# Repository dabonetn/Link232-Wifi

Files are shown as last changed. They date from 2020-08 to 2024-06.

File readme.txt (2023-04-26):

Usage Notes

BBS Host Mode.
The current BBS host mode enables a local echo by default, so to make it actually work with bbs software, when you enable
bbs host in the at+config menu, in the bbs host submenu, make sure echo is set to off.

128 Users. I noticed on DESTERM and Dialogue 128, that if you have the modem set to hangup on DTR drop,
the modem will hang up trying to download. To disable this function, enter the command
ats54=2 then press enter, then at&w then enter to save it to the modem.
After this, you have to use the +++, wait and then ATH for hangup on your side.

Main Readme.

Link232-Wifi, Swift-L and Swift-T

This project covers the Link232 and Swiftlink RS232 carts combined with the zimodem firmware.
It has my Cartridge version, along with the Internal Versions for the 128, 128DCR and C64 longboard.

Link232-Wifi
This is a Swiftlink compatible High Speed Uart cartridge for the Commodore 64/128.
Because it's a link232 clone, it only uses 16 bytes of the dXXX address space, and you can set it using the solder jumpers. 
You must cut the dx00 link and then connect the solder jumper you want the new address to be.

Swift-T
This is a Swiftlink compatible internal wifi modem for the c64 longboard and the 128DCR.
It plugs into a socket at U2 and then you install the 6526 into the modem board.
Flying leads then connect the IO address (DE00 or DF00) and Dotclock.
On the 128DCR, it plugs in U1, and has one more flying lead to connect the NMI line. (Total of 3)

Swift-L
This is a Swiftlink compatible internal wifi modem for the C128 flat model.
It plugs into a socket at U2 and then you install the 6526 into the modem board.
Flying leads then connect the IO address (DE00/DF00/Or D700) and Dotclock.

All of them use swiftlink drivers in your favorite terminal program/bbs.
CCGMS/Novaterm/Desterm/etc.. 

For Centipede 128 BBS software, new Swiftlink drivers for address DF00 and D700 are located under the SoftwarePatches directory.
(It only had DE00 by default)

Premade units are usually available on ebay from me.

https://www.ebay.com/sch/tndabone/m.html?_nkw=&_armrs=1&_ipg=&_from=

Default for most programs is DE00/NMI

Modem commands are under the Zimodem directory.

I'm merging the Internal Units and the Cartridge version under this page. As all 3 use the same firmware.

Much thanks to Dr. Evil Laboratories for designing the original Swiftlink Cart.
And to Jim Brain for the Link232 design,
And of course Bo Zimmerman for the very excellent Zimodem firmware.

Please see the quick start guide if you bought a prebuilt cart.

Default setting for a new unit from me is.

DE00/NMI

19200 Baud
Hardware Flow Control (CTS/RTS)

The current zimodem firmware is forked from version "3.7.0"

To update to the current firmware use the command

at&u6502

For usage of zimodem, see the readme in the zimodem directory.
Link232-Wifi is based off the ESP-12, not the ESP32, so No esp32 only features will work.

Changes I've made.

In Zimodem.ino I've set 19200 baud as standard, and got rid of the signal inversion while using a ESP8266 module.

Zcommand.ino mainly has me replacing the zimmers.net with dabone.xyz to prevent a update and bricking of the Link232-Wifi.
Telnet protocol on atdt dialing has been disabled by default ""telnetSupport=false;""
To renable telnet translation by the modem instead of the terminal, use the command ats62=1.

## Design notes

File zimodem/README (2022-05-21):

Zimodem 3.6.4 (C)2016-2021 Bo Zimmerman
Please read the LICENSE file for license information
Please read the NOTICE file for credits information

Intro:
------
This firmware code provides an api for communication between a serial terminal and the ESP8266 or ESP32.  It simulates the old-style Hayes "AT" commands, so that the ESP8266 appears to the terminal as if it were a Hayes modem.  These "AT" commands may then be issued to the ESP8266 in order to force it to connect to a wireless access point, and from there to make one or more manageable connections to the internet.  It also includes a streaming serial "telnet" mode, and server/port listener capabilities.

The default baud rate that the firmware establishes is 1200.  Be sure to use the commands below to set this to the proper baud rate for your terminal/host computer.  If you plan on using the Commodore 8-bit utilities, keep the firmware baud rate saved at 1200.

Building:
---------
To build this firmware for the ESP-01 or ESP-12, I used the Arduino IDE rev1.8.10 with the 2.7.4 Arduino ESP8266 libraries using the Generic ESP8266 Module.  Versions newer than 2.7.4 may not work.  Install the libraries from the Boards Manager using http://arduino.esp8266.com/stable/package_esp8266com_index.json. Both versions of the firmware are built with SPIFFS enabled.  On the ESP8266, I used settings of 1M/160k, but you may want to alter that depending on your hardware and needs. 

To build this firmware for the ESP-32, I also used the Arduino IDE rev 1.8.10 with the Arduino ESP32 Dev Module installed from the board manager * , with the following settings: QIO, 4MB, 80MHZ, 921600, NONE, Avrisp Mk II **.  I found that baud changing corrupts the serial bus as of 1/13/2018, so the following changes were made to the base libraries: 
> Added to esp32-hal-uart.c:
void uartChangeBaudRate(uint8_t uart_nr, uint32_t baudrate)
{ 
    uartSetBaudRate(&_uart_bus_array[uart_nr], baudrate); 
}
void uartChangeConfig(uint8_t uart_nr, uint32_t config)
{
    uart_t* uart = &_uart_bus_array[uart_nr];
    UART_MUTEX_LOCK();
    uart->dev->conf0.val = config;
    #define TWO_STOP_BITS_CONF 0x3
    #define ONE_STOP_BITS_CONF 0x1

    if ( uart->dev->conf0.stop_bit_num == TWO_STOP_BITS_CONF) {
        uart->dev->conf0.stop_bit_num = ONE_STOP_BITS_CONF;
        uart->dev->rs485_conf.dl1_en = 1;
    }
    UART_MUTEX_UNLOCK();
}
size_t uartWritesRemaining(uart_t* uart)
{
    if(uart == NULL) {
        return 0;
    }
    size_t remain;
    UART_MUTEX_LOCK();
    remain = 0x7F - uart->dev->status.txfifo_cnt;
    UART_MUTEX_UNLOCK();
    return remain;
}
> Added to esp32-hal-uart.h:
void uartChangeBaudRate(uint8_t uart_nr, uint32_t baudrate);
void uartChangeConfig(uint8_t uart_nr, uint32_t config);
size_t uartWritesRemaining(uart_t* uart);
> Added to HardwareSerial.cpp:
void HardwareSerial::changeBaudRate(int baudRate) { uartChangeBaudRate(_uart_nr, baudRate); }
void HardwareSerial::changeConfig(uint32_t config) { uartChangeConfig(_uart_nr, config); }
> Added to HardwareSerial.h:
void changeBaudRate(int baudRate);
void changeConfig(uint32_t config);

* On the ESP32, if you want to build firmware that is Update compatible with the official production zimodem, you'll need to install the exact libraries I use from http://www.zimmers.net/otherprojs/esp32_v0.zip .  If you don't care about that, using the latest libs work just fine.

Using:
------
Upon initialization, or any time the ESP module is reset, the modem will display its version, and some information about the host hardware, and then read a configuration file from the internal SPIFFS to re-establish the previously set baud rate, and to attempt to re-connect to the previously connected wireless router.  The first time it is run, the firmware will set a baud rate of 1200 and display INITALIZED to let you know that no previous wifi configuration was found.  Once the serial terminal displays READY, it is ready to receive commands.  

The first command you'll probably want to enter is AT+CONFIG to connect to a wireless router, and set your flow control and other command mode settings.

Afterwards, if you plan to use this primarily from a computer that doesn't need linefeeds, such as the C64, you'll want to enter ATR0 to go into carriage-return only mode, and then at&w to save this setting as well.

If you want to operate at a higher baud, you'll want to enter ATB9600 (or whatever baud rate you want to try), and then reconnect your terminal program to the modem at that new baud rate.  If everything looks good, and you want to keep the new baud rate across restarts, save the new baud rate with AT&W.  Warning though: Most of the example C64 programs assume the modem defaults to 1200 baud.

If you want to connect to a remote telnet server, eg coffeemud.net, port 23, you'll want to enter ATDT"coffeemud.net:23".  Don't forget to set your terminal program to the proper translation mode (ANSI, ASCII, or whatever).

If you are using a Commodore Graphics terminal program and want to connect to a Commodore BBS, eg cottonwoodbbs.dyndns.org port 6502, you'll want to enter ATD"cottonwoodbbs.dyndns.org:6502".

If you want to use Q-Link, you need to add a phone number alias first.  To do this, enter ATP"5551212=q-link.net:5190" or enter it from the config menu AT+CONFIG. From the C64 Q-Link client, select "Hayes compatible" 1200 baud modem when prompted.

If you want to run a Commodore BBS program using the modem, you'll want to configure the BBS program to the same idle baud rate that your modem is using (1200 baud by default), configure it for a Hayes style modem (or the C=1670), and either create a persistant listener using AT+CONFIG, or use an initialization string of "ATR0E0S0=1S41=1A6400" plus any other recommended settings from the BBS program. This creates a listener at port 6400 that switches directly to stream mode on the first ring, with no linefeed carriage returns, and no keystroke echo.  Your BBS program may require you add certain other settings, such as V0 or X1.. which you should also do.

If you want to try printing to a CUPS/IPP-printer, enter AT+PRINT?:<host>:<port>/<path>, followed by your data.  Where ? is A)scii, P)etscii, or R)aw.  A 5 second pause in incoming data completes the document and returns to command mode.  Example: AT+PRINTR:192.168.1.10:631/ipp/printer  -- followed by ENTER and then the data to print, without any pause longer than 5 seconds.  Subsequent to doing this, using AT+PRINT will repeat the previous URL.

ESP32 Guru Modem users with SD-cards can enter AT+SHELL to get a shell command prompt.  Enter ? to get a list of shell commands.

Command Set:
-----------

The command set is as follows (not case sensitive):

ATZ : closes all open socket connections (preserving the Access Point connection), stops all listeners, and resets the state of the Command processor to the saved configuration, preserving the current baud rate and wifi connection.

A/ : Repeats the previous command

ATI : re-shows the startup message, including wifi connection information.
ATI0 : same as ATI
ATI1 : Shows the current common variable settings, common 'S' registers.
ATI2 : Shows the modem's current IP address
ATI3 : Shows the modem's current Wireless Router connection
ATI4 : Shows only the firmware current version
ATI5 : Shows all the current variable settings, all 'S' registers.
ATI6 : Shows the current mac address.
ATI7 : Shows the current formatted time (see AT&T).
ATI8 : Shows the firmware build date/time
ATI9 : Same as I3, but also includes any static settings, same order as ATW
ATI10: Shows the last printer url used.

ATA  : If a server listener has generated a RING, then ATA will switch the last rung connection to Stream mode (see ATD).

ATAn : Causes the modem to create a server listening on port n.  When a connection is received, the terminal will generate 1 or more RINGs according to the ATS0 register, followed by a normal CONNECT respose. At this point, all other commands related to connections may be used normally, unless ATS41 is > 0, in which case incoming connections are automatically sent to Stream mode as per ATD or ATA. Listeners are listed along with other connections using ATC0.
ATAPn : Adding a P modifier causes all incoming connection input to be translated to PETSCII
ATATn : Adding a T modifier causes connection streaming input to be translated per TELNET when the changed to Stream mode
ATAEn : Adding a E modifier causes connection terminal echo to be enabled when the changed to Stream mode
ATAXn : Adding a X modifier causes connection XON/XOFF flow control to be enabled  when the changed to Stream mode.

ATN0 : Shuts down all listeners, leaving client connections open
ATNn : if n > 0 then same as ATAn

ATE0 : Turns serial terminal echo off for command mode.
ATE1 : Turns serial terminal echo on for command mode.

ATV0 : Turns off verbose responses mode (Uses Terse Numeric response mode)
ATV1 : Turns on verbose responses mode (Uses Word response mode)

ATX0 : Turns off extended response codes (1/CONNECT instead of 5/CONNECT 2, etc..)
ATX1 : Turns on extended response codes (5/CONNECT 2 instead of 1/CONNECT, etc..)

ATF0 : Turns on rts/cts flow control.
ATF1 : Turns on xon/xoff flow control.
ATF2 : Turns on xon/xoff flow control, sets XON mode (if necessary), and, in command mode, will immediately go to XOFF when a single connection packet is received. This is very useful when the client wants to ensure it only receives one packet to process.  You can think of this as an alternative way to use xon/xoff by having XOFF automatic between packets.
ATF3 : Similar to ATF2 except that the default is XOFF, and, in command mode, a XON code from the user will immediately trigger either an empty packet response [ 0 0 0 ], or a real packet if one is available.  After this, as in ATF2, XOFF is automatically set.
ATF4 : Turns off flow control for command mode

ATQ0 : Turns off quiet mode (Sends response codes)
ATQ1 : Turns on quiet mode (Stops sending response codes)

ATR0 : Suppresses linefeed (\n $0a) in end of lines.  Will only send carriage return (\r $0d).
ATR1 : Sends \r\n ($0d0a) as end of line string.
ATR2 : Sends \n\r ($0a0d) as end of line string.
ATR3 : Suppresses carriage return (\r $0d) in end of lines.  Will only send linefeed (\n $0a).

ATBn : Sets a new serial Baud Rate. Takes effect immediately.
ATB"n,xYz" : Sets baud rate n, bits x, parity (E,O,M, or N) for Y, and stop bits z.

ATW : List all wireless network access points scanned within range.  The response for each entry is the SSID, following by the RSSI, followed by an * character is the connection is encrypted.
ATWn : Where n > 0, this lists up to n wireless network access points scanned within range.  The response for each entry is the SSID, following by the RSSI, followed by an * character is the connection is encrypted.
ATW"[SSI],[PASSWORD]" : Connects to the wireless access point with the given SSI, using the given password.
ATW"[SSI],[PASSWORD],[IP],[DNS],[GATEWAY],[SUBNET]" : as ATW, but with more options
ATWP : Adding a P modifier is the same as all forms of ATW, with both arguments and results presented in PETSCII.

ATD : Start a streaming connection between the current opened connection.  Use "+++" to exit back to Command mode.
ATDn : Where n > 0, this will start a streaming connection between the previously opened connection with an id the same as n.  Use "+++" to exit back to Command mode.
ATD"[HOSTNAME]:[PORT]" : This opens a streaming connection between the terminal and the given host/port. Use "+++" to disconnect and exit back to command mode.
ATDP"[HOSTNAME]:[PORT]" : Adding a P modifier causes connection input to be translated to PETSCII during the streaming session.
ATDT"[HOSTNAME]:[PORT]" : Adding a T modifier causes connection input to be translated per TELNET during the streaming session.
ATDE"[HOSTNAME]:[PORT]" : Adding a E modifier causes terminal echo to be enabled that streaming session.
ATDX"[HOSTNAME]:[PORT]" : Adding a X modifier causes XON/XOFF flow control to be enabled that streaming session.
ATDnnnnnnn : Where n=0-9, if the digits exist in the phonebook (see ATP), it will try connect to that host, with those modifiers, from the phonebook.

ATC : Shows information about the current network connection in the following format "[CONNECTION STATE] [CONNECTION ID] [CONNECTED TO HOST]:[CONNECTED TO PORT]"
ATC0 : Lists information about all of the network connections in the following format "[CONNECTION STATE] [CONNECTION ID] [CONNECTED TO HOST]:[CONNECTED TO PORT]", including any Server (ATA) listeners.
ATCn : Where n > 0, this changes the Current connection to the one with the given ID.  If no connection exists with the given id, ERROR is returned.
ATC"[HOSTNAME]:[PORT]" : Creates a new connection to the given host and port, assigning a new id if the connection is successful, and making this connection the new Current connection.  The quotes and colon are required.
ATCP"[HOSTNAME]:[PORT]" : Adding a P modifier causes all connection input to be translated to PETSCII
ATCT"[HOSTNAME]:[PORT]" : Adding a T modifier causes streaming input to be translated per TELNET when the changed to Stream mode
ATCE"[HOSTNAME]:[PORT]" : Adding a E modifier causes terminal echo to be enabled when the changed to Stream mode
ATCX"[HOSTNAME]:[PORT]" : Adding a X modifier causes XON/XOFF flow control to be enabled  when the changed to Stream mode

ATH  : Hangs up (disconnects and deletes) all open connections.  Does not close Server listeners.
ATH0 : Hangs up (disconnects and deletes) the current opened connection.
ATHn : Hangs up (disconnects and deletes) the open connection with the given id.  Closing a Server (ATA) listener does not close any connections received from that listener.

ATO : Re-enters a Streaming session (see ATD) under the previous settings, with the current (previous) connection.

ATP : Lists all existing phonebook entries, with the format phone number followed by ATD modifiers, followed by the host and port.  Add ? to also get notes.
ATP"[NUMBER]=[HOSTNAME]:[PORT],[NOTES]" : Adds or Modifies an entry to the phonebook with the given 7 digit number, host, port, and notes. Use ATDnnnnn.. to connect.
ATPP"[NUMBER]=[HOSTNAME]:[PORT],[NOTES]" : Adding a P modifier causes connection input to be translated to PETSCII  when connected to that entry.
ATPT"[NUMBER]=[HOSTNAME]:[PORT],[NOTES]" : Adding a T modifier causes connection input to be translated per TELNET  when connected to that entry.
ATPE"[NUMBER]=[HOSTNAME]:[PORT],[NOTES]" : Adding a E modifier causes terminal echo to be enabled when connected to that entry.
ATPX"[NUMBER]=[HOSTNAME]:[PORT],[NOTES]" : Adding a X modifier causes XON/XOFF flow control to be enabled when connected to that entry.
ATP"[NUMBER]=DELETE" : Removes the phonebook entry with the given number.

ATS0=n : Changes the number of RING messages received before a CONNECT response is sent, on incoming Server listeners.
ATS1=n : Unimplemented, always returns OK
ATS2=n : Change the escape character (n = 0-255), Defaults to ASCII decimal 43 ("+")
ATS3=n : Change the Carriage Return Character   (n = 0-127), Defaults to ASCII decimal 13 (Carriage Return)
ATS4=n : Change the Line Feed Character (0-127), Defaults ASCII decimal 10 (Line Feed)
ATS5=n : Change the Backspace Character (0-32), ASCII decimal 8 (Backspace)
ATS6 ... 39=n : Unimplemented, always returns OK
ATS40=n : Change the size of the connection packets (n > 0), Defaults to 127 bytes
ATS41=n : When n > 0, all incoming Server listener connections are immediately sent to Stream mode.  If n=0, connections remain in normal command mode (default).
ATS42=n : Set the CRC8 for an attached Transmit command.  e.g. ATS42=123T"[MESSAGE]" returns error unless 123 is CRC8 of "[MESSAGE]".
ATS43=n : Sets a standby baud rate n for the next incoming or outgoing connection only.  ATZ clears.
ATS44=n : Sets an automatic delay of n milliseconds after most bytes written to the Serial port.  This is for computers that support a baud rate, but can't really keep up, and you don't want to use flow control.
ATS45=n : Changes how packet and at&g data is delivered.  0 is normal binary with normal headers, 1 is 78 char HEX digit streams followed by EOLN with hex digit headers, 2 is decimal digits followed by EOLN, with decimal digit headers, 3 is normal without SUM header.
ATS46=n : Changes DCD status. n=0 is default DCD=HIGH=online. n=1 is DCD=LOW=online. n=2 always HIGH. n=3 always LOW.
ATS47=n : Changes DCD pin number, n=2 is default
ATS48=n : Changes CTS status. n=0 is default CTS=HIGH=active. n=1 is CTS=LOW=active. n=2 always HIGH. n=3 always LOW.
ATS49=n : Changes CTS pin number, n=0 is default on ESP01, and default is 5 otherwise
ATS50=n : Changes RTS status. n=0 is default RTS=HIGH=active. n=1 is RTS=LOW=active. n=2 always HIGH. n=3 always LOW. (N/A on ESP01)
ATS51=n : Changes RTS pin number, n=4 is default (N/A on ESP01)
ATS52=n : Changes RI status. n=0 is default RI=HIGH=active. n=1 is RTS=LOW=active. n=2 always HIGH. n=3 always LOW. (N/A on ESP01)
ATS53=n : Changes RI pin number, n=14 is default (N/A on ESP01)
ATS54=n : Changes DTR status. n=0 is default DTR=HIGH=active. n=1 is RTS=LOW=active. n=2 always HIGH. n=3 always LOW. (N/A on ESP01)
ATS55=n : Changes DTR pin number, n=12 is default (N/A on ESP01)
ATS56=n : Changes DSR status. n=0 is default DSR=HIGH=active. n=1 is RTS=LOW=active. n=2 always HIGH. n=3 always LOW. (N/A on ESP01)
ATS57=n : Changes DSR pin number, n=13 is default (N/A on ESP01)
ATS60=n : When n > 0, immediately saves existing listeners and automatically restores them later. n=0 to clear.
ATS61=n : When n > 0, sets the number of seconds to timeout a print job stream (AT+PRINT). Default is 5 seconds
ATS62=n : When n > 0, enables/disables telnet support in the ATD (Dial) command. Default is 1 (enabled).

+++ : With a 1 second pause with no other characters afterwards, this will disconnect the current opened connection.

ATT"[MESSAGE]" : Transmit the given text string, with \r\n at the end, on the current connection.
ATTn : Where n > 0, this starts a transmit of exactly n bytes to the current connection.  The \n from entering this command must be followed by the n bytes to transmit.
ATTP"[MESSAGE]" : Transmit the given text string, translating petscii to ascii, with \r\n at the end, on the current connection.
ATTPn : Where n > 0, this starts a transmit of exactly n bytes to the current connection, translating petscii to ascii.  The \n from entering this command must be followed by the n bytes to transmit.
ATT+"[MESSAGE] : A + argument may be used to force the 'T' command to return the CRC8 of the message instead of OK, when successful.

ATL0  : Re-sends the most recently sent data packet again
ATLn  : Re-sends the most recently sent data packet for connection id n.

AT&H  : Shows a help file from the web, or brief help otherwise.  Use &H6502 to reiforce web download.
AT&L  : Reloads the saved configuration.
AT&W  : Saves the current configuration: WiFi settings(ATW), baud rate (ATB), end of line (ATR) settings, flow control (ATF), echo mode (ATE), extended responses (ATX), verbose responses (ATV), quiet responses (ATQ), PETSCII mode (AT&P1), pin statuses (ATS46 - S58), Rings (ATS0), Listener Stream-mode (ATS41), and Listener restore (ATS60), printer spec (AT+PRINT), and busy message.
AT&F  : Restores the modem to factory default settings.  Use &F86 to reformat the SPIFFS.
AT&On : n is 1 to turn on internal serial-reception log, n is 0 to turn off or view a previously turned-on log, n is 88 to turn on ESP32 debug port.
AT&U  : Checks the firmware home page to see if a new version is available.
AT&U6502 : Will update the firmware from the home page on the web.
AT&U=x: Will update the firmware from the web to custom version x.
AT&Kn : Flow Control, similar to ATFn, n=0,1,2: disable, n=3,6: rts/cts, n=4,5: Xon/Xoff
AT&Pn : Where n > 0, all command mode input and output will be translated to/from PETSCII before internal processing.  This will not affect received packet data, or the stream mode.
AT&Nx : Shows the status of ESP module I/O pin x
AT&Mn : Adds the byte denoted by n to a list of mask-out bytes.  These are bytes that are not transmitted to the serial port in command mode incoming packets.  If this command is followed by a C, N, or A command on the SAME LINE, then the setting will apply ONLY to that connection or listener.
AT&M  : Resets the mask-out bytes list. No bytes will be masked-out. If this command is followed by a C, N, or A command on the SAME LINE, then the setting will apply ONLY to that connection or listener.
AT&Dn : Adds the byte denoted by n to a list of delimiter bytes.  These are bytes that will compose the last byte in a command-mode incoming packet that is still shorter than the limit set by ATS40. This is useful for CR-LF formatted data.  If this command is followed by a C, N, or A command on the SAME LINE, then the setting will apply ONLY to that connection or listener.
AT&D  : Resets the delimiter bytes list. No bytes will be delimited, and packets will contain as many bytes as are received and allowed by ATS40.  If this command is followed by a C, N, or A command on the SAME LINE, then the setting will apply ONLY to that connection or listener.

AT&S"40=[HOSTNAME]" : Change the modem hostname
AT&S"41=[TERMTYPE]" : Change the telnet 'termtype' response string
AT&S"42=[BUSYMSG]" : Change the stream connection 'busy message'

AT&T"[TIMEZONE],[TIME FORMAT],[NTP URL]" : set up the NTP clock. DISABLE to disable. Format is like Java SimpleDateFormat, but with % escapes. Each argument is optional.
AT&G"[HOSTNAME]:[PORT]/[FILENAME]" : Streams a file from an HTTP source on the internet.  The header contains channel 0, file length, and an 8-bit sum of all the bytes in the forthcoming file, followed by the bytes of the file, all formatted as a normal packet.  An ASCII 3 (CNTRL-C) received during the transfer will abort. The S44 register can be used to create artificial delays in this output.  XON/XOFF Flow control also remains in effect with, on a byte-by-byte basis for the auto and manual flow control systems. Requires flash space for caching, or S45=3 to eliminate the SUM header.
AT&Y  : Resets the state machine string. No state machine will be executed.
AT&Yn : Change the current state (for command mode AND current connection) to state n, where n is a decimal number.
AT&Y"[CODED STATE MACHINE]" : Adds the coded format string to a state machine.  If this command is followed by a C, N, or A command on the SAME LINE, then the setting will apply ONLY to that connection or listener.   State Machine Format: MMcCCNN ...  States are numbered by their order in the list starting with 00.  Non-matches automatically go to the next state until a match is made.   'MM' is hex byte to match (or 00 to match all).  'c' is one of these commands :e=eat byte, p=push byte to que, d=send byte, q=send all queued, x=flush queue, r=replace with byte represented by hex CC.  'C' is either '-', one of the command letters above, or a hex byte value if the first command was 'r'.  'NN' is the next state to go to, with 00 being the first state.

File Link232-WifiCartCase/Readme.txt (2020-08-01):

These were based off the Customizable Commodore 64 Cartridge using Openscad and then Tinkercad.
Link to case.
https://www.thingiverse.com/thing:1702546

Link232-Wifi-TopCase.stl
I've been printing the top of the case text up, because on a glass bed, it's way too shiny.

Link232-Wifi-cartridge-bottom.stl
This is the standard screw for the Customizable Commodore 64 Cartridge, I didn't have anything that fit so did the next one.

Link232-Wifi-BottomCase-Number4screw.stl
This uses a US size 4x5/8 screw to secure the case.

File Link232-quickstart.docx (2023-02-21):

Link232-Wifi

Quickstart

The Link232-Wifi comes preset with the following configuration.

IO=DE00, NMI, Baud Rate: 19200,Flow Control: CTS/RTS

Your terminal MUST MATCH the IO. So for example CCGMS lists Swift / Turbo DE,

Swift / Turbo DF, and Swift / Turbo D7 for IO addresses DE00, DF00, and D700.

To Change IO/NMI move the jumpers on the cartridge pcb.

IRQ is usually only used on CP/M.

For quick setup type AT+CONFIG then enter.

WEP security protocol isn’t supported, Standard WPA is.

I recommend setting up in ASCII emulation instead of PETSCII. Some Wifi Passwords don’t seem to enter correctly in PETSCII.

Sample dial commands

atd”host.com:6400

This will call host.com at port 6400.

atdnnnnnn (n=0-9, if the number exists in the modem phone book, it will dial with the phonebook settings for host, flow control, translation, etc.

You can add a phonebook entry using the at+config menu, or

ATP"[NUMBER]=[HOSTNAME]:[PORT],[NOTES]" : Adds or Modifies an entry to the phonebook with the given 7 digit number, host, port, and notes.

Full modem command listings is located at

https://github.com/dabonetn/Link232-Wifi/tree/master/zimodem

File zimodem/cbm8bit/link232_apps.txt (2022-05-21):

/**************************
/* Link232 WiFi Software  *
/* for the Commodore 64   *
/**************************
///////////////////////////

This disk includes applications written to work with the Link232 WiFi modem running firmware version 2.0 or better. If this is your first time using the modem, you should start with the configure program to get your modem connected to the internet.  You can then use the FTP, TELNET, IRC, WGET, and other programs whenever you wish to communicate with the internet.  The disk includes numerous machine language binaries (pml64.bin, and swiftdrvr.bin) which are required for some the several programs provided.

The disk includes the source assembly code for the pml64 and the SwiftLink Kernal Wedge driver binary.  These source files are in LADS format.  The disk also includes the LADS assembler for the C64 to re-assemble the binaries from the source files.  To use the LADS assembler, you should use a C64 or C128 in C64 mode, and load the LADS assembler using LOAD"LADS",8,1.  Once the assembler is loaded, clear the screen and type the name of the source file to assemble in the upper left-hand corner of the screen.  Once that is done, use SYS11000 to begin the assembly, which will create the .bin files.

The disk lastly includes the program "emutil", which is a C64, C128, or VIC-20 program to creating and dissolving .D64 images, such as those downloaded by the d64wget program discussed below. 

Below you will find information on the application programs included on this disk, as well as instructions on using the PML64, PML128, PMLVIC, and UP9600 machine language libraries from BASIC or machine language.

CONFIGURE
*************************************

The Configure program is for setting up or altering the WiFi Hotspot, also known as a Wireless Internet Router, that your modem uses to communicate with the internet.  It also allows you to modify the modems built in phone book.  It is written in BASIC, but uses the PML64.BIN  libraries for speed (see below).  This program requires a C64 or C128 in 64 mode and your Link232 WiFi Modem configured for 19200 baud, which is the default factory configuration.  To run the program, enter LOAD"CONFIGURE",8  and then RUN.

When the program runs, it will initialize the Link232 modem with certain commands.  If you receive an error at this point, or if the program hangs for longer than a minute, try turning your computer off and on again to clear memory and reset the modem, and then load and run it again.

After initialization, the program will scan the area for WiFi Hotspots and provide you a list to select from.  If you do not see your own wireless router listed, or do not know the name, consult your ISP's internet equipment documentation.  After you have selected the appropriate hotspot, you will be prompted for the password.  After the password is entered, the program will test the settings and, if successful, save the settings to the flash memory in your modem  it will be remembered even after the computer is turned off.  When wifi configuration is complete, and the modem passes the connection test, you can modify the modems internal phone book. 

The modems internal phone book maintains a list of numbers and associated internet addresses and configurations.  These numbers can then be used by third party software to 'dial' to those sites using the modems ATD command.  A phone number, in this case, is any large number, preferably 7 digits or more, that is assigned to a particuler internet host and port.  Each host can then be configured for ASCII-PETSCII translation, TELNET code translation, XON/XOFF flow control, and/or local ECHO (half vs full duplex).  Every modification you make is saved to the modem and available after reboots.  This system can be used to connect to the online Q-Link service online using the existing Q-Link software.

FTP
*************************************

File Transfer Protocol program supports a minimal number of features to connect to FTP Servers all over the internet in order to download and/or upload programs.  It is written in BASIC, but uses PML64.BIN and SWIFTDRVR.BIN. 

This program requires a C64 or C128 in 64 mode, and your Link232 WiFi Modem configured for 19200 baud, which is the default factory configuration.  To run the program, enter LOAD"FTP",8  and then RUN.

When you start the program, it will initialize your Link232 modem with certain commands.  If you receive an error at this point, or if the program hangs for longer than a minute, try turning your computer off and on again to clear memory and reset the modem, and then load and run it again.

After initialization, you will be given a menu where you can enter the host name of the ftp server to connect to, and the login and password to use.  If you plan to login with the name "anonymous", you should use your email address as your password.  The last option on the menu is the drive number to upload files from and download files to.  When all options are correct, hit RETURN to connect.

At the FTP prompt, you may enter one of the following commands:

DIR : list the files in the current directory
CD [DIRECTORY OR PATH] : change to a new directory
QUIT : exit the ftp program
HELP : show the commands supported by the client and the server
GET [FILENAME,P] : download the program with the name filename as a PRG.  Use ,S for SEQ.
PUT [FILENAME,P] : upload the program with the name filename which is a PRG file. Use ,S for SEQ.
DEL [FILENAME] : delete the given file from the server
LCD [DEVICE NUMBER or CMD Hard Drive PATH] : change the active local upload/download drive, or change which directory you are using if the active drive is a UIEC or CMD Hard Drive compatible.
LDIR [MASK] : get a directory of the active local drive.
LDEL [FILENAME] : delete the given local file from the active drive.

WGET
*************************************

WGET program is for downloading files and pages from a standard HTTP web address (URL).  It is written in BASIC, but uses PML64.BIN and SWIFTDRVR.BIN.

This program requires a C64 or C128 in 64 mode, and your Link232 WiFi Modem configured for 19200 baud, which is the default factory configuration. To run the program, enter LOAD"WGET",8  and then RUN.

When you start the program, it will initialize your Link232 modem with certain commands.  If you receive an error at this point, or if the program hangs for longer than a minute, try turning your computer off and on again to clear memory and reset the modem, and then load and run it again.

After initialization, you will be given a menu where you can enter the url of the file or page to download, the unit number of the disk drive to download the file or page to, and the name of the file to write to the disk.  Your filename should end with ,P to create a PRG file, and ,S to create a SEQ file.  For example, a filename of "mypage,s" will create a file called "mypage" of type SEQ.  When all options are correct, hit RETURN to connect and begin the download.  When the download completes, the program will exit.

IRC
*************************************

IRC program is for chatting with people on free internet IRC Servers.  It is written in BASIC, but uses the PML64.BIN, PMLVIC.BIN, or PML128.BIN libraries for speed (see below). This program requires a C64 or C128 in 64 mode, and your Link232 WiFi Modem configured for 19200 baud, which is the default factory configuration. To run the program, enter LOAD"IRC",8  and then RUN.

When you start the program, it will initialize your Link232 modem with certain commands.  If you receive an error at this point, or if the program hangs for longer than a minute, try turning your computer off and on again to clear memory and reset the modem, and then load and run it again.

After initialization, you will be asked to enter the host name of the IRC Server to connect to.  Next you will be prompted for the port number that the server listens on.  The program will then attempt to connect to the host and port.  If successful, you will be prompted to enter a nickname, which is the name you will be known by during chatting.  If your nickname is already in use by someone else, you will eventually be prompted to enter a new one.  Either way, the program will display the servers MOTD and other information.  This could take several minutes.  It's best to just wait until you see the message "End of MOTD" to begin typing.

After the MOTD message, you may type at any time.  If you have joined a chat channel, you will automatically see messages as they appear in the channel.  When you begin typing, all messages from the server are suspended until you hit RETURN.  Since the IRC client will appear to the server to be idle while you are typing, it is best to spend as little time as necessary in messaage and command entry mode.  You may enter ? followed by RETURN to see the IRC commands supported by this client.  

Commands include:
/QUIT : exit the IRC chat program
/JOIN #channelname : join the new channel named "#channelname"
* Anything else entered will be assumed to be a message to sent to the channel you have already joined.

TELNET
*************************************

TELNET program is for communicating with a TELNET server as a terminal, or with a TELNET-like server such as a Multi-User Dungeon game (a MUD).  It is written in BASIC, but uses the PML64.BIN, PMLVIC.BIN, or PML128.BIN libraries for speed (see below).  This program requires a C64 or C128 in 64 mode, and your Link232 WiFi Modem configured for 19200 baud, which is the default factory configuration. To run the program, enter LOAD"TELNET",8  and then RUN.

When you start the program, it will initialize your Link232 modem with certain commands.  If you receive an error at this point, or if the program hangs for longer than a minute, try turning your computer off and on again to clear memory and reset the modem, and then load and run it again.

After initialization, you will be shown a menu with the following options:

Dial from Phonebook: 
This will let you connect to a server saved in your phonebook on disk.  See below for information about terminal mode while connected to a server

Modify Phonebook:
This will let you add or modify servers to save in your phonebook on disk.  These can be then "Dialed" to quickly later on.

Quick Connect:
This will let you manually enter a server host name and port to immediately connect to.  See below for information about terminal mode while connected to a server.

Terminal Mode: 
This will put you into terminal mode without connecting to any server.  In this case, you would be in the modem firmware's Command Mode.  You should consult the documentation for the Link232 WiFi Firmware for more information on this mode.  Use the F1 key or the C128's ESC key to exit terminal mode.

Quit:
Exit the TELNET program

When you have connected to a server, you will be in ANSI terminal mode.  You can exit the server and disconnect at any time by hitting the F1 key on your C64, or the ESC key on your C128.  When connected to a server, the modem will translate as much ASCII/ANSI into mostly viewable PETSCII for your Commodore computer.  However, you will notice that underscores look like back-arrows.  ANSI colors will be translated to Commodore PETSCII colors wherever possible.  Your own keystrokes will also be translated to ASCII/ANSI as you type.  

CBMTERM
*************************************

C= TERM program is for communicating with a telnet-style Commodore Graphics BBS servers as a terminal.  It is written in BASIC, but uses PML64.BIN and SWIFTDRVR.BIN.  This program requires a C64 or C128 in 64 mode, and your Link232 WiFi Modem configured for 19200 baud, which is the default factory configuration.  To run the program, enter LOAD"CBMTERM",8  and then RUN.

When you start the program, it will initialize your Link232 modem with certain commands.  If you receive an error at this point, or if the program hangs for longer than a minute, try turning your computer off and on again to clear memory and reset the modem, and then load and run it again.

After initialization, you will be shown a menu with the following options:

Dial from Phonebook: 
This will let you connect to a server saved in your phonebook on disk.  See below for information about terminal mode while connected to a server

Modify Phonebook:
This will let you add or modify servers to save in your phonebook on disk.  These can be then "Dialed" to quickly later on.  You will receive an option for a Host Name, a Port Number, and Local Echo.  Consult your online BBS list for hosts and ports of the BBSes you wish to connect to.  The Local Echo option should usually be answered with NO, as most BBSes will echo for you, and having the modem do local echo will corrupt X-Modem transfers.

Quick Connect:
This will let you manually enter a server host name and port to immediately connect to.  See below for information about terminal mode while connected to a server.

Terminal Mode: 
This will put you into terminal mode without connecting to any server.  In this case, you would be in the modem firmware's Command Mode.  You will be prompted as to whether you would like Local Echo turned on.  If you plan to remain in Command Mode and not connect to anything, you can say Yes.  However, if you plan to connect to a BBS, or especially if you plan to do any file transfers, you should definitely answer NO.  You should consult the documentation for the Link232 WiFi Firmware for more information on this mode.  Use the F1 key or the C128's ESC key to exit terminal mode.  See below for more you can do after exiting terminal mode.

Quit:
Exit the CBMBBS program

When you have connected to a server, you will be in CBM PETSCII/Graphics mode.  You can exit the terminal at any time by hitting the F1 key on your C64, or the ESC key on your C128.  If you are offline, you will immediately return to the main menu.  However, if you are still online, you will have the option to hangup and return to the main menu, upload a file using X-Modem CRC, download a file, or continue back to terminal mode.

D64WGET
*************************************

D64WGET program is for downloading and writing full emulator disk images (such as .D64, .D71, .D81, .DNP, etc) files from a standard HTTP web address (URL) and write them to a formatted, blank diskette.  It is written in BASIC, but uses PML64.BIN and SWIFTDRVR.BIN.

This program requires a C64 or C128 in 64 mode, and your Link232 WiFi Modem configured for 19200 baud, which is the default factory configuration.  To run the program, enter LOAD"D64WGET",8  and then RUN.

When you start the program, it will initialize your Link232 modem with certain commands.  If you receive an error at this point, or if the program hangs for longer than a minute, try turning your computer off and on again to clear memory and reset the modem, and then load and run it again.

After initialization, you will be given a menu where you can enter the url of the disk image file to download and write, and the unit number of the disk drive containing the *formatted* blank disk to write the image to.  When all options are correct, hit RETURN and answer Y to the confirmation to connect and begin the download and disk write.  When the download completes, which could take awhile, the program will exit.

PML64.BIN
*************************************

This file for the C64 in 128 mode is a machine language support file for performing certain common Link232 modem functions from BASIC.  PML64.BIN loads to $C000 (49152).

To use them from BASIC, make sure to follow two important rules: 1. Load the appropriate binary into memory (pml64.bin).  and 2. Initialize the variable p$, by giving it some value, as early in your program as possible.  For example: P$="" would be fine.

Throughout this section, I will refer to the variable ML to refer to the starting address of the library.  For the C64, this is always 49152.  So, when I say ML+3, I mean 49155 on the C64.

---------
BUF1LIN

Usage:
sys ML

Pre-requisites: 
P$ must be initialized in BASIC
Channel 5 must be OPEN to the modem

Outputs:
P$ contains the string line read from the modem, if any
ML + 19 is 0 to denote success, or 255 for a timeout
ML + 26 contains the CRC8 value of the received string

Description:
Reads from the open modem channel until a carriage return (13) is seen, or until 255 characters are read, or until a timeout occurs.  The characters are returned in the BASIC variable P$, although character values 10 and 0 are always ignored.  The timeout is about 12 seconds.

---------
BUFXLIN

Usage:
sys ML+3

Pre-requisites: 
P$ must be initialized in BASIC
Channel 5 must be OPEN to the modem
ML + 18 contains the number of bytes to read

Outputs:
P$ contains the X bytes read from the modem if any
ML + 18 contains the number of bytes NOT read (0 on success)
ML + 19 is 255 for a timeout, or any other value for the index of the last carriage return (13) in the returned buffer.
ML + 26 contains the CRC8 value of the received bytes

Reads from the open modem channel until the number of bytes in ML+18 have been read, or until 253 bytes are read, or until a timeout occurs.  The bytes are returned in the BASIC variable P$.  The timeout is about 12 seconds.

---------
GETPACKET

Usage:
sys ML+6

Pre-requisites: 
P$ must be initialized in BASIC
Channel 5 must be OPEN to the modem

Outputs:
ML + 18 contains the number of bytes read
ML + 19 is 255 for a timeout or packet formatting error
ML + 20 is the packet/channel ID that sent the data (0=none)
ML + 22 is the size of the packet received
ML + 24 is the EXPECTED CRC8 of the packet data sent by the modem
ML + 26 contains the CRC8 value of the received string

Reads a special Link232 WiFi Firmware formatted Packet from modem channel. This function will block until it times out, or a packet is received, so it's best used with the ATF3 flow control to ensure that every time XON is sent to the modem, a single packet header is guarenteed to be sent to the computer. When this method returns, ML+19 should be checked for an error, ML+22 for a non-0 to see if any data was received, or ML+20 to make sure it matches the expected channel (this can be 0 for a non-response when using ATF3).  You can also optionally compare ML+26 to ML+24 to check for RS232 errors.

---------
CRCP

Usage:
sys ML+9

Pre-requisites: 
P$ contains the string to calculate the CRC of

Outputs:
ML + 26 contains the CRC8 value of the received string

Description:
Calculates the CRC8 of P$ and returns it.

---------
BUFAP

Usage:
sys ML+12

Pre-requisites: 
P$ must be initialized in BASIC
ML + 32 contains the channel number to read from
The above channel must be open

Outputs:
P$ contains the bytes read from the channel, if any
ML + 26 contains the CRC8 value of the received bytes

Description:
Reads from the open channel whose number is contained in ML+32 until no more bytes are available, or until 254 bytes are read.  The bytes are returned in the BASIC variable P$.

SWIFTDRVR.BIN
*************************************

This file is the SwiftLink/Turbo232 BASIC wedge driver for the C64.  Use SYS51200 to activate.  After this point, all device 2 access will go to the SwiftLink/Turbo232 cartridge instead of the user port.
The baud rate codes used in the OPEN command are compatible with the C64 KERNAL, with additions:
00000 (bit value of 0)   = Nonstandard (User-Defined) Rate (Not Implemented)
00001 (bit value of 1)   = 50 Baud  (Not supported)
00010 (bit value of 2)   = 75 Baud  (Not supported)
00011 (bit value of 3)   = 110 Baud  (Not supported)
00100 (bit value of 4)   = 134.5 Baud  (Not supported)
00101 (bit value of 5)   = 150 Baud  (Not supported)
00110 (bit value of 6)   = 300 Baud
00111 (bit value of 7)   = 600 Baud
01000 (bit value of 8)   = 1200 Baud
01001 (bit value of 9)   = 1800 Baud  (Not supported)
01010 (bit value of 10)  = 2400 Baud
01011 (bit value of 11)  = 3600 Baud
01100 (bit value of 12)  = 4800 Baud
01101 (bit value of 13)  = 7200 Baud
01110 (bit value of 14)  = 9600 Baud
01111 (bit value of 15)  = 19200 Baud
10000 (bit value of 16)  = 38400 Baud
10001 (bit value of 17)  = 57600 Baud (Turbo232 only)
10010 (bit value of 18)  = 115200 Baud (Turbo232 only)
10011 (bit value of 19)  = 230400 Baud (Turbo232 only)

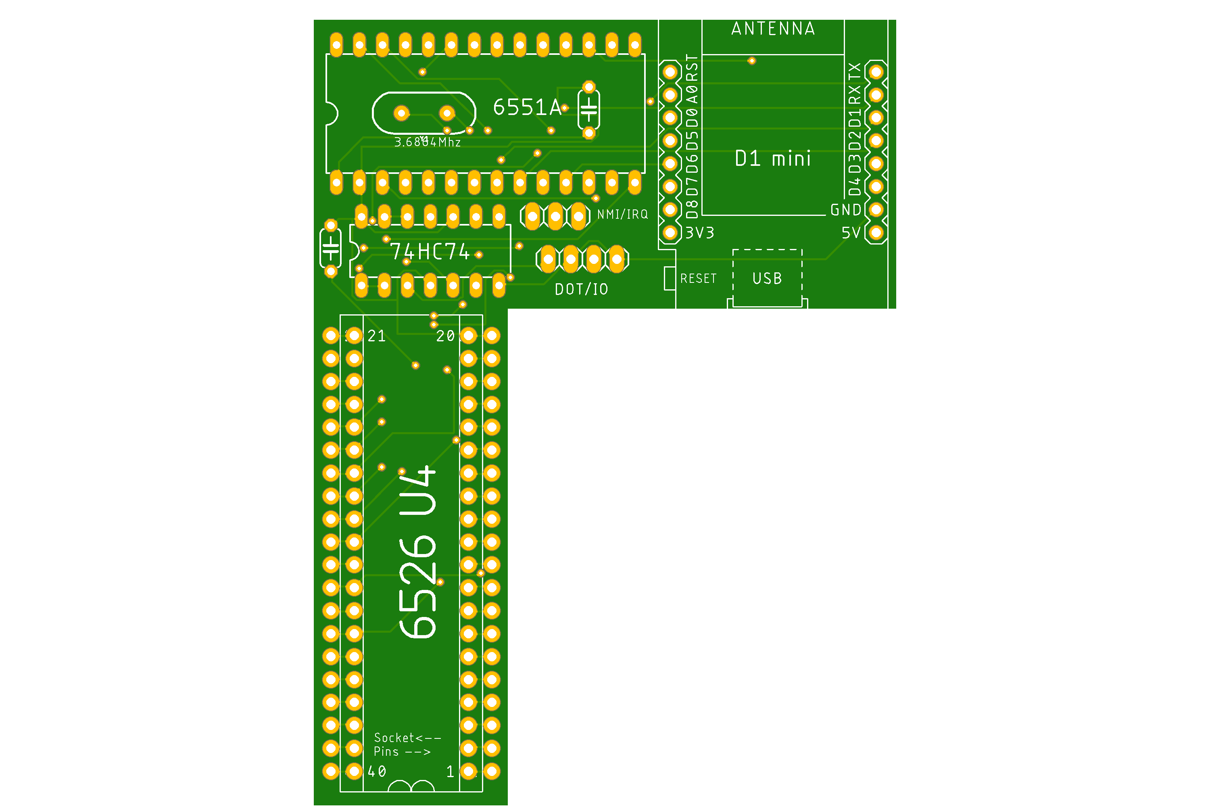
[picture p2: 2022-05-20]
eagle files/Swift-L (C128)/Swiftl1.3.png

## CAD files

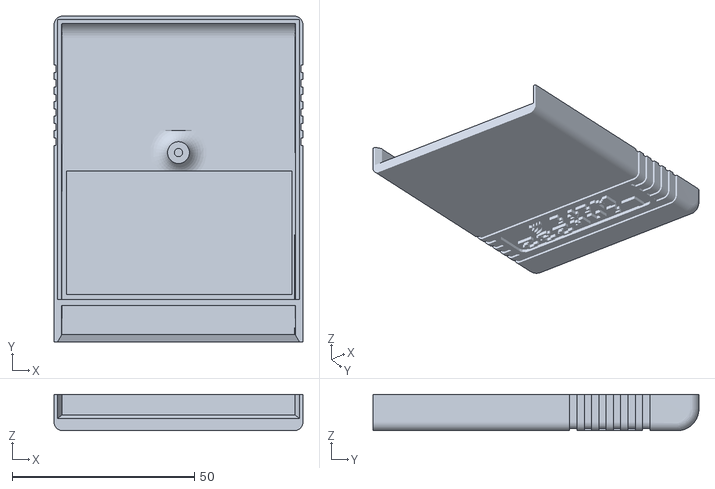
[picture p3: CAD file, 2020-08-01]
Link232-WifiCartCase/Link232-Wifi-TopCase.stl
68.4 x 89.5 x 10.0

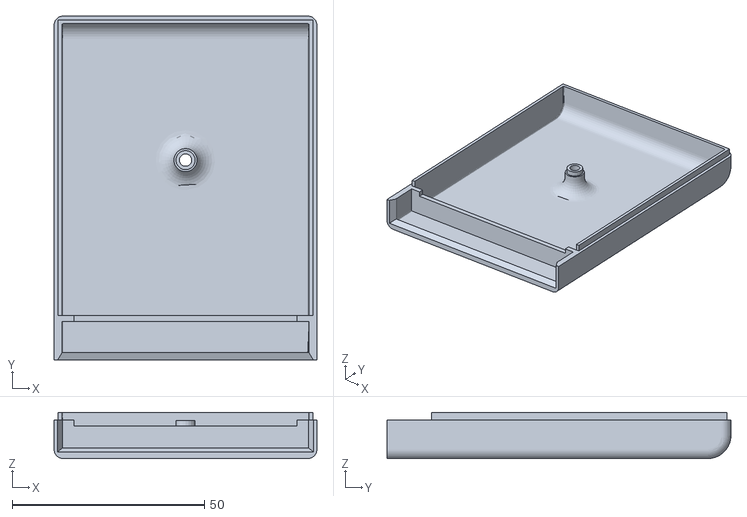
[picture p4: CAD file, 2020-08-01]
Link232-WifiCartCase/Link232-Wifi-BottomCase-Number4screw.stl
68.4 x 89.5 x 12.0

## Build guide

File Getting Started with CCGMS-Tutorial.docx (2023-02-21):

Quick start terminal guide for Link-232-Wifi Zimodem firmware modem.

First start by getting a copy of CCGMS Future, it’s available at https://github.com/mist64/ccgmsterm/releases

Load it up and you will be greeted with the following screen.

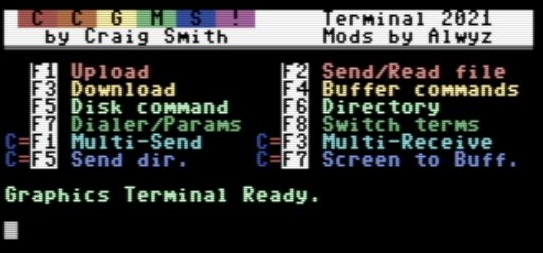
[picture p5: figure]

The default for the Link-232-Wifi Cart is DE00/NMI. So let’s set the terminal program to talk to the modem. Press F7, for the following menu.

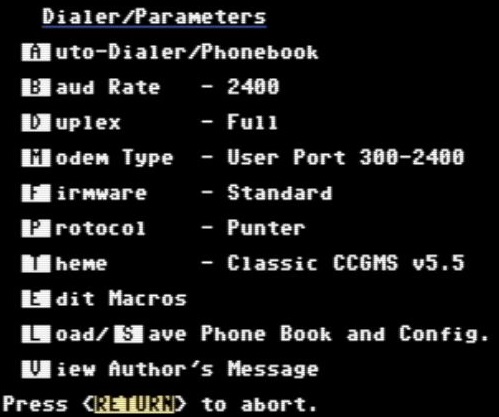
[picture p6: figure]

Press M until the Modem Type reads like in the picture below.

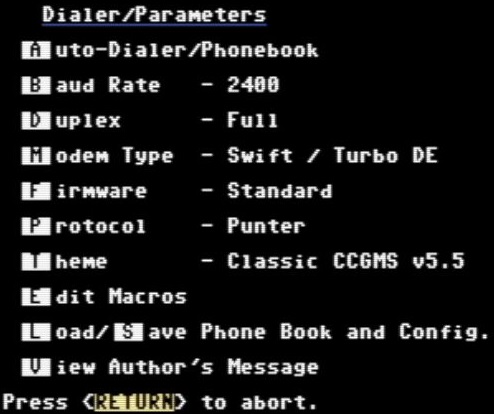
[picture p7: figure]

Now modem type is Swift / Turbo DE, that means the modem is at DE00.

If your modem is at DF00, then the type is Swift/Turbo DF

If your modem is at D700 (Internal modems only), then the type is Swift/Turbo D7

Now that the modem type is correct, change the baud rate to 19200, by pressing B until 19200 appears.

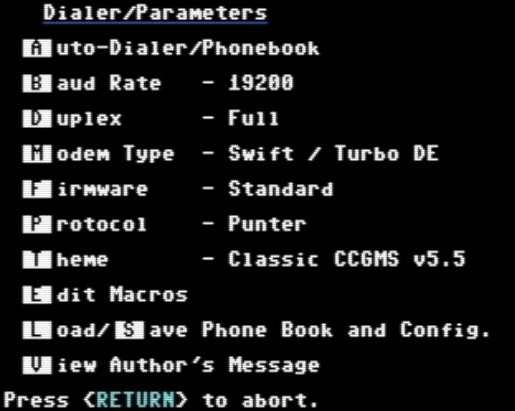
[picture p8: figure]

Now set the firmware type to Zimodem. This changes the dial command to atd, instead of atdt.

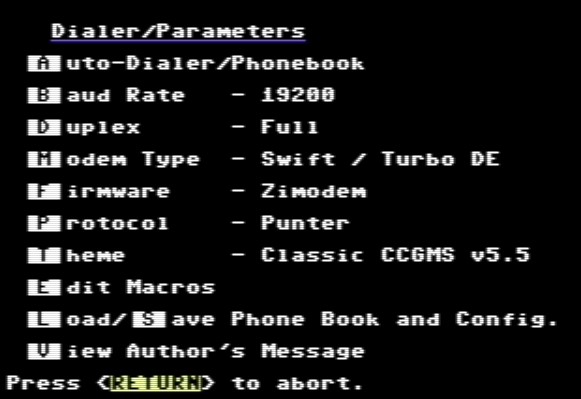
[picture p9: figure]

Now press S to save the config.

Just press return to leave the default filename of ccgms-phone.

Now press Return to exit to terminal mode.

Now press F8 to get to the ASCII terminal mode. It shows as follows.

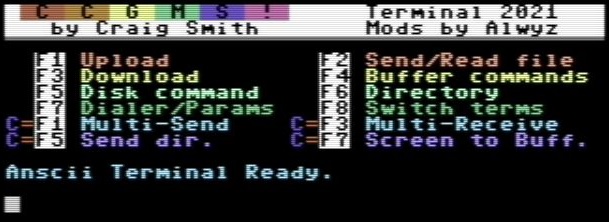
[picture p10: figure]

Now type at+config and press enter to access the modem config menu.

If the Link232-Wifi is connected and working correctly, you should get the following screen.

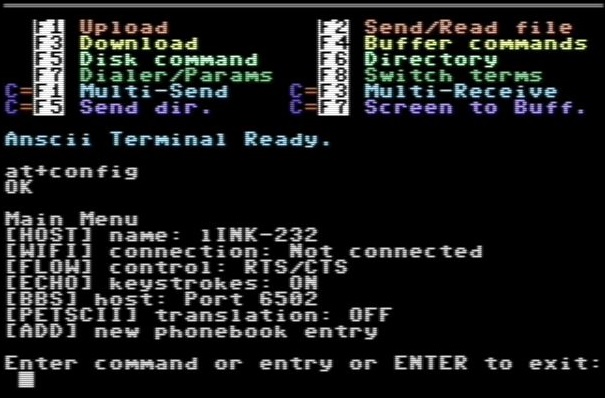
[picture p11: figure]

Press w, then press Return to connect to a wifi access point.

This will list all the access points that the modem sees.

(The following pics have been edited to remove peoples last names that they put in their SSIDs..)

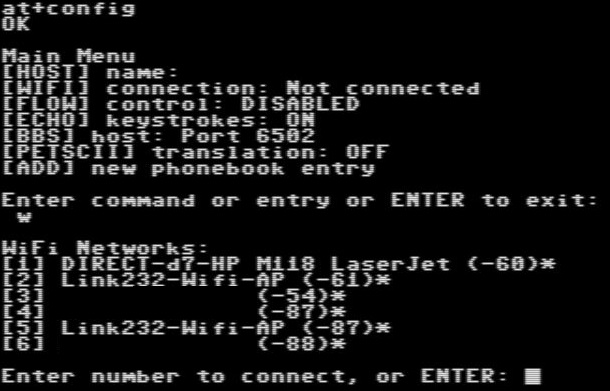
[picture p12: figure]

Here I have 2 access points with the name Link232-Wifi-AP. The lower the number in (), the stronger the signal.

Enter the number for your access point and press enter.

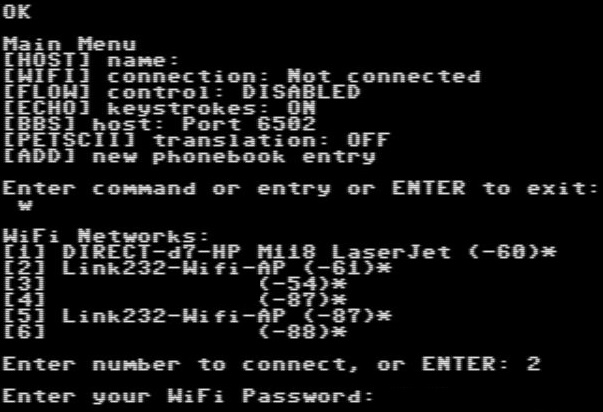
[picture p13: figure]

Now enter your password, then press enter. (Password is shown as you type)

After password, you get a DHCP question.

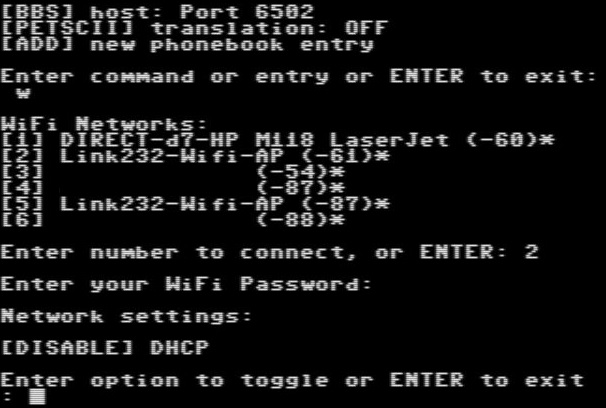
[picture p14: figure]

If you ARE NOT setting a fixed ip, just press enter here. For fixed IP, the menu options are the usual IP, Netmask, DNS and gateway. (Note, earlier versions of the firmware don’t have the DISABLE DHCP option.)

The Main Menu will return, and to save, press enter without an option, it will then ask if you want to save.

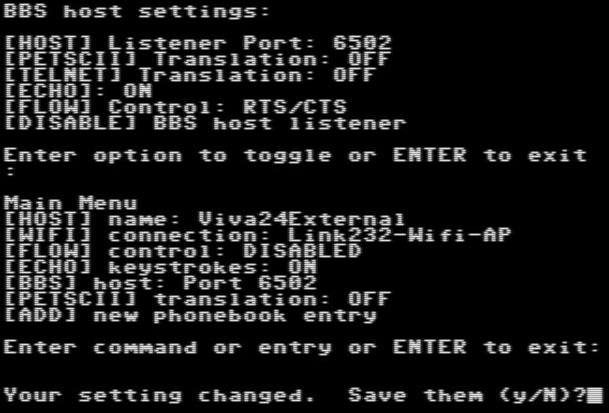
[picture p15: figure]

Now press F8 to go back to PETSCII mode.

The press F7, and save the terminal setting to PETSCII (press s)

The Press return to get back to the terminal.

For a quick test I like calling theoldnet.com, it’s a Commodore compatible BBS running on a PI.

Just enter

atd”theoldnet.com:6400

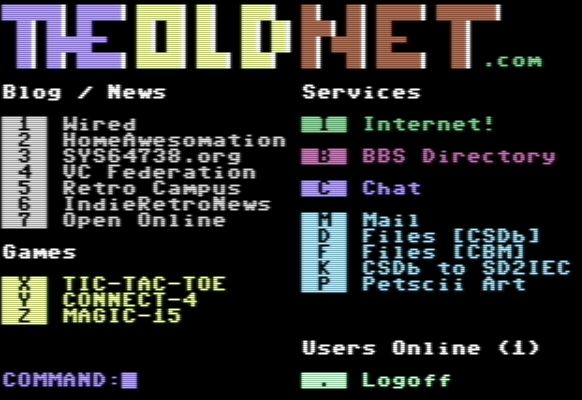
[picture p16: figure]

The Firmware on the Link232-Wifi is based on Zimodem, which is still in constant development.

To update your Link232-Wifi, the command is at&u6502. This will download and install the latest tested firmware from my server.

Here are the basic AT commands for the Link232-Wifi

Command Set:

The command set is as follows (not case sensitive):

ATZ : closes all open socket connections (preserving the Access Point connection), stops all listeners, and resets the state of the Command processor to the saved configuration, preserving the current baud rate and wifi connection.

A/ : Repeats the previous command

ATI : re-shows the startup message, including wifi connection information.

ATI0 : same as ATI

ATI1 : Shows the current common variable settings, common 'S' registers.

ATI2 : Shows the modem's current IP address

ATI3 : Shows the modem's current Wireless Router connection

ATI4 : Shows only the firmware current version

ATI5 : Shows all the current variable settings, all 'S' registers.

ATI6 : Shows the current mac address.

ATI7 : Shows the current formatted time (see AT&T).

ATI8 : Shows the firmware build date/time

ATI9 : Same as I3, but also includes any static settings, same order as ATW

ATI10: Shows the last printer url used.

ATA : If a server listener has generated a RING, then ATA will switch the last rung connection to Stream mode (see ATD).

ATAn : Causes the modem to create a server listening on port n. When a connection is received, the terminal will generate 1 or more RINGs according to the ATS0 register, followed by a normal CONNECT respose. At this point, all other commands related to connections may be used normally, unless ATS41 is > 0, in which case incoming connections are automatically sent to Stream mode as per ATD or ATA. Listeners are listed along with other connections using ATC0.

ATAPn : Adding a P modifier causes all incoming connection input to be translated to PETSCII

ATATn : Adding a T modifier causes connection streaming input to be translated per TELNET when the changed to Stream mode

ATAEn : Adding a E modifier causes connection terminal echo to be enabled when the changed to Stream mode

ATAXn : Adding a X modifier causes connection XON/XOFF flow control to be enabled when the changed to Stream mode.

ATN0 : Shuts down all listeners, leaving client connections open

ATNn : if n > 0 then same as ATAn

ATE0 : Turns serial terminal echo off for command mode.

ATE1 : Turns serial terminal echo on for command mode.

ATV0 : Turns off verbose responses mode (Uses Terse Numeric response mode)

ATV1 : Turns on verbose responses mode (Uses Word response mode)

ATX0 : Turns off extended response codes (1/CONNECT instead of 5/CONNECT 2, etc..)

ATX1 : Turns on extended response codes (5/CONNECT 2 instead of 1/CONNECT, etc..)

ATF0 : Turns on rts/cts flow control.

ATF1 : Turns on xon/xoff flow control.

ATF2 : Turns on xon/xoff flow control, sets XON mode (if necessary), and, in command mode, will immediately go to XOFF when a single connection packet is received. This is very useful when the client wants to ensure it only receives one packet to process. You can think of this as an alternative way to use xon/xoff by having XOFF automatic between packets.

ATF3 : Similar to ATF2 except that the default is XOFF, and, in command mode, a XON code from the user will immediately trigger either an empty packet response [ 0 0 0 ], or a real packet if one is available. After this, as in ATF2, XOFF is automatically set.

ATF4 : Turns off flow control for command mode

ATQ0 : Turns off quiet mode (Sends response codes)

ATQ1 : Turns on quiet mode (Stops sending response codes)

ATR0 : Suppresses linefeed (\n $0a) in end of lines. Will only send carriage return (\r $0d).

ATR1 : Sends \r\n ($0d0a) as end of line string.

ATR2 : Sends \n\r ($0a0d) as end of line string.

ATR3 : Suppresses carriage return (\r $0d) in end of lines. Will only send linefeed (\n $0a).

ATBn : Sets a new serial Baud Rate. Takes effect immediately.

ATB"n,xYz" : Sets baud rate n, bits x, parity (E,O,M, or N) for Y, and stop bits z.

ATW : List all wireless network access points scanned within range. The response for each entry is the SSID, following by the RSSI, followed by an * character is the connection is encrypted.

ATWn : Where n > 0, this lists up to n wireless network access points scanned within range. The response for each entry is the SSID, following by the RSSI, followed by an * character is the connection is encrypted.

ATW"[SSI],[PASSWORD]" : Connects to the wireless access point with the given SSI, using the given password.

ATW"[SSI],[PASSWORD],[IP],[DNS],[GATEWAY],[SUBNET]" : as ATW, but with more options

ATWP : Adding a P modifier is the same as all forms of ATW, with both arguments and results presented in PETSCII.

ATD : Start a streaming connection between the current opened connection. Use "+++" to exit back to Command mode.

ATDn : Where n > 0, this will start a streaming connection between the previously opened connection with an id the same as n. Use "+++" to exit back to Command mode.

ATD"[HOSTNAME]:[PORT]" : This opens a streaming connection between the terminal and the given host/port. Use "+++" to disconnect and exit back to command mode.

ATDP"[HOSTNAME]:[PORT]" : Adding a P modifier causes connection input to be translated to PETSCII during the streaming session.

ATDT"[HOSTNAME]:[PORT]" : Adding a T modifier causes connection input to be translated per TELNET during the streaming session.

ATDE"[HOSTNAME]:[PORT]" : Adding a E modifier causes terminal echo to be enabled that streaming session.

ATDX"[HOSTNAME]:[PORT]" : Adding a X modifier causes XON/XOFF flow control to be enabled that streaming session.

ATDnnnnnnn : Where n=0-9, if the digits exist in the phonebook (see ATP), it will try connect to that host, with those modifiers, from the phonebook.

ATC : Shows information about the current network connection in the following format "[CONNECTION STATE] [CONNECTION ID] [CONNECTED TO HOST]:[CONNECTED TO PORT]"

ATC0 : Lists information about all of the network connections in the following format "[CONNECTION STATE] [CONNECTION ID] [CONNECTED TO HOST]:[CONNECTED TO PORT]", including any Server (ATA) listeners.

ATCn : Where n > 0, this changes the Current connection to the one with the given ID. If no connection exists with the given id, ERROR is returned.

ATC"[HOSTNAME]:[PORT]" : Creates a new connection to the given host and port, assigning a new id if the connection is successful, and making this connection the new Current connection. The quotes and colon are required.

ATCP"[HOSTNAME]:[PORT]" : Adding a P modifier causes all connection input to be translated to PETSCII

ATCT"[HOSTNAME]:[PORT]" : Adding a T modifier causes streaming input to be translated per TELNET when the changed to Stream mode

ATCE"[HOSTNAME]:[PORT]" : Adding a E modifier causes terminal echo to be enabled when the changed to Stream mode

ATCX"[HOSTNAME]:[PORT]" : Adding a X modifier causes XON/XOFF flow control to be enabled when the changed to Stream mode

ATH : Hangs up (disconnects and deletes) all open connections. Does not close Server listeners.

ATH0 : Hangs up (disconnects and deletes) the current opened connection.

ATHn : Hangs up (disconnects and deletes) the open connection with the given id. Closing a Server (ATA) listener does not close any connections received from that listener.

ATO : Re-enters a Streaming session (see ATD) under the previous settings, with the current (previous) connection.

ATP : Lists all existing phonebook entries, with the format phone number followed by ATD modifiers, followed by the host and port. Add ? to also get notes.

ATP"[NUMBER]=[HOSTNAME]:[PORT],[NOTES]" : Adds or Modifies an entry to the phonebook with the given 7 digit number, host, port, and notes. Use ATDnnnnn.. to connect.

ATPP"[NUMBER]=[HOSTNAME]:[PORT],[NOTES]" : Adding a P modifier causes connection input to be translated to PETSCII when connected to that entry.

ATPT"[NUMBER]=[HOSTNAME]:[PORT],[NOTES]" : Adding a T modifier causes connection input to be translated per TELNET when connected to that entry.

ATPE"[NUMBER]=[HOSTNAME]:[PORT],[NOTES]" : Adding a E modifier causes terminal echo to be enabled when connected to that entry.

ATPX"[NUMBER]=[HOSTNAME]:[PORT],[NOTES]" : Adding a X modifier causes XON/XOFF flow control to be enabled when connected to that entry.

ATP"[NUMBER]=DELETE" : Removes the phonebook entry with the given number.

ATS0=n : Changes the number of RING messages received before a CONNECT response is sent, on incoming Server listeners.

ATS1=n : Unimplemented, always returns OK

ATS2=n : Change the escape character (n = 0-255), Defaults to ASCII decimal 43 ("+")

ATS3=n : Change the Carriage Return Character (n = 0-127), Defaults to ASCII decimal 13 (Carriage Return)

ATS4=n : Change the Line Feed Character (0-127), Defaults ASCII decimal 10 (Line Feed)

ATS5=n : Change the Backspace Character (0-32), ASCII decimal 8 (Backspace)

ATS6 ... 39=n : Unimplemented, always returns OK

ATS40=n : Change the size of the connection packets (n > 0), Defaults to 127 bytes

ATS41=n : When n > 0, all incoming Server listener connections are immediately sent to Stream mode. If n=0, connections remain in normal command mode (default).

ATS42=n : Set the CRC8 for an attached Transmit command. e.g. ATS42=123T"[MESSAGE]" returns error unless 123 is CRC8 of "[MESSAGE]".

ATS43=n : Sets a standby baud rate n for the next incoming or outgoing connection only. ATZ clears.

ATS44=n : Sets an automatic delay of n milliseconds after most bytes written to the Serial port. This is for computers that support a baud rate, but can't really keep up, and you don't want to use flow control.

ATS45=n : Changes how packet and at&g data is delivered. 0 is normal binary with normal headers, 1 is 78 char HEX digit streams followed by EOLN with hex digit headers, 2 is decimal digits followed by EOLN, with decimal digit headers, 3 is normal without SUM header.

ATS46=n : Changes DCD status. n=0 is default DCD=HIGH=online. n=1 is DCD=LOW=online. n=2 always HIGH. n=3 always LOW.

ATS47=n : Changes DCD pin number, n=2 is default

ATS48=n : Changes CTS status. n=0 is default CTS=HIGH=active. n=1 is CTS=LOW=active. n=2 always HIGH. n=3 always LOW.

ATS49=n : Changes CTS pin number, n=0 is default on ESP01, and default is 5 otherwise

ATS50=n : Changes RTS status. n=0 is default RTS=HIGH=active. n=1 is RTS=LOW=active. n=2 always HIGH. n=3 always LOW. (N/A on ESP01)

ATS51=n : Changes RTS pin number, n=4 is default (N/A on ESP01)

ATS52=n : Changes RI status. n=0 is default RI=HIGH=active. n=1 is RTS=LOW=active. n=2 always HIGH. n=3 always LOW. (N/A on ESP01)

ATS53=n : Changes RI pin number, n=14 is default (N/A on ESP01)

ATS54=n : Changes DTR status. n=0 is default DTR=HIGH=active. n=1 is RTS=LOW=active. n=2 always HIGH. n=3 always LOW. (N/A on ESP01)

ATS55=n : Changes DTR pin number, n=12 is default (N/A on ESP01)

ATS56=n : Changes DSR status. n=0 is default DSR=HIGH=active. n=1 is RTS=LOW=active. n=2 always HIGH. n=3 always LOW. (N/A on ESP01)

ATS57=n : Changes DSR pin number, n=13 is default (N/A on ESP01)

ATS60=n : When n > 0, immediately saves existing listeners and automatically restores them later. n=0 to clear.

ATS61=n : When n > 0, sets the number of seconds to timeout a print job stream (AT+PRINT). Default is 5 seconds

+++ : With a 1 second pause with no other characters afterwards, this will disconnect the current opened connection.

ATT"[MESSAGE]" : Transmit the given text string, with \r\n at the end, on the current connection.

ATTn : Where n > 0, this starts a transmit of exactly n bytes to the current connection. The \n from entering this command must be followed by the n bytes to transmit.

ATTP"[MESSAGE]" : Transmit the given text string, translating petscii to ascii, with \r\n at the end, on the current connection.

ATTPn : Where n > 0, this starts a transmit of exactly n bytes to the current connection, translating petscii to ascii. The \n from entering this command must be followed by the n bytes to transmit.

ATT+"[MESSAGE] : A + argument may be used to force the 'T' command to return the CRC8 of the message instead of OK, when successful.

ATL0 : Re-sends the most recently sent data packet again

ATLn : Re-sends the most recently sent data packet for connection id n.

AT&H : Shows a help file from the web, or brief help otherwise. Use &H6502 to reiforce web download.

AT&L : Reloads the saved configuration.

AT&W : Saves the current configuration: WiFi settings(ATW), baud rate (ATB), end of line (ATR) settings, flow control (ATF), echo mode (ATE), extended responses (ATX), verbose responses (ATV), quiet responses (ATQ), PETSCII mode (AT&P1), pin statuses (ATS46 - S58), Rings (ATS0), Listener Stream-mode (ATS41), and Listener restore (ATS60), printer spec (AT+PRINT), and busy message.

AT&F : Restores the modem to factory default settings. Use &F86 to reformat the SPIFFS.

AT&On : n is 1 to turn on internal serial-reception log, n is 0 to turn off or view a previously turned-on log, n is 88 to turn on ESP32 debug port.

AT&U : Checks the firmware home page to see if a new version is available.

AT&U6502 : Will update the firmware from the home page on the web.

AT&U=x: Will update the firmware from the web to custom version x.

AT&Kn : Flow Control, similar to ATFn, n=0,1,2: disable, n=3,6: rts/cts, n=4,5: Xon/Xoff

AT&Pn : Where n > 0, all command mode input and output will be translated to/from PETSCII before internal processing. This will not affect received packet data, or the stream mode.

AT&Nx : Shows the status of ESP module I/O pin x

AT&Mn : Adds the byte denoted by n to a list of mask-out bytes. These are bytes that are not transmitted to the serial port in command mode incoming packets. If this command is followed by a C, N, or A command on the SAME LINE, then the setting will apply ONLY to that connection or listener.

AT&M : Resets the mask-out bytes list. No bytes will be masked-out. If this command is followed by a C, N, or A command on the SAME LINE, then the setting will apply ONLY to that connection or listener.

AT&Dn : Adds the byte denoted by n to a list of delimiter bytes. These are bytes that will compose the last byte in a command-mode incoming packet that is still shorter than the limit set by ATS40. This is useful for CR-LF formatted data. If this command is followed by a C, N, or A command on the SAME LINE, then the setting will apply ONLY to that connection or listener.

AT&D : Resets the delimiter bytes list. No bytes will be delimited, and packets will contain as many bytes as are received and allowed by ATS40. If this command is followed by a C, N, or A command on the SAME LINE, then the setting will apply ONLY to that connection or listener.

AT&S"40=[HOSTNAME]" : Change the modem hostname

AT&S"41=[TERMTYPE]" : Change the telnet 'termtype' response string

AT&S"42=[BUSYMSG]" : Change the stream connection 'busy message'

AT&T"[TIMEZONE],[TIME FORMAT],[NTP URL]" : set up the NTP clock. DISABLE to disable. Format is like Java SimpleDateFormat, but with % escapes. Each argument is optional.

AT&G"[HOSTNAME]:[PORT]/[FILENAME]" : Streams a file from an HTTP source on the internet. The header contains channel 0, file length, and an 8-bit sum of all the bytes in the forthcoming file, followed by the bytes of the file, all formatted as a normal packet. An ASCII 3 (CNTRL-C) received during the transfer will abort. The S44 register can be used to create artificial delays in this output. XON/XOFF Flow control also remains in effect with, on a byte-by-byte basis for the auto and manual flow control systems. Requires flash space for caching, or S45=3 to eliminate the SUM header.

AT&Y : Resets the state machine string. No state machine will be executed.

AT&Yn : Change the current state (for command mode AND current connection) to state n, where n is a decimal number.

AT&Y"[CODED STATE MACHINE]" : Adds the coded format string to a state machine. If this command is followed by a C, N, or A command on the SAME LINE, then the setting will apply ONLY to that connection or listener. State Machine Format: MMcCCNN ... States are numbered by their order in the list starting with 00. Non-matches automatically go to the next state until a match is made. 'MM' is hex byte to match (or 00 to match all). 'c' is one of these commands :e=eat byte, p=push byte to que, d=send byte, q=send all queued, x=flush queue, r=replace with byte represented by hex CC. 'C' is either '-', one of the command letters above, or a hex byte value if the first command was 'r'. 'NN' is the next state to go to, with 00 being the first state.

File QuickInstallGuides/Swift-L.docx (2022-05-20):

Swift-L Quick install guide for the Commodore 128 flat.

Start by removing the CIA chip at U4. It’s on the left side down from the user port. Then insert the Swift-L into the socket, wifi module to the rear of the machine. The plug the cia into the socket of the Swift-L. (Notch towards the front of the machine.)

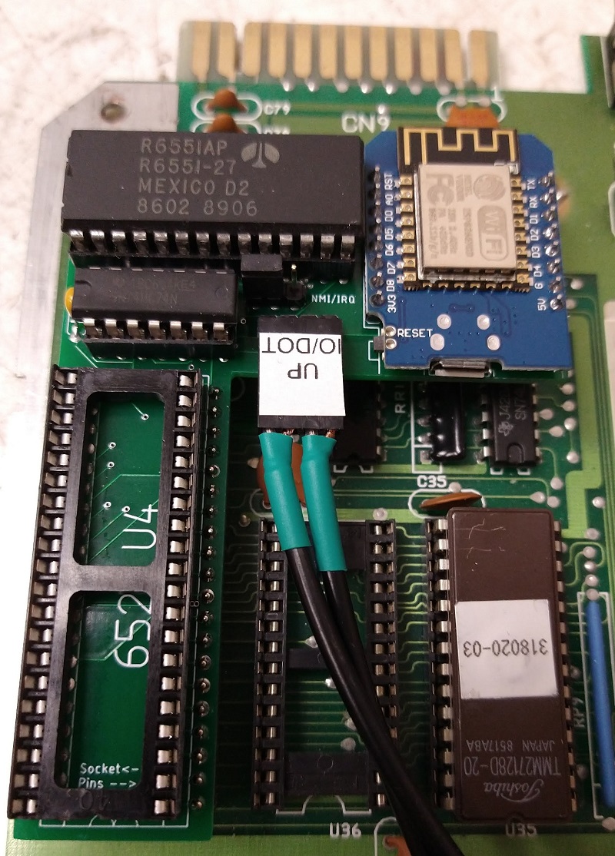
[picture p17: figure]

After removing the chip, insert the Swift-t into the socket, wifi module to the rear of the machine.

Now double check which wire is which. The Left cable is to the dot clock, right cable is IO addressing. Make sure your cable is plugged in the with the label visible.

Dot Clock has 2 possible connection points. Pin 6 on the cartridge port.

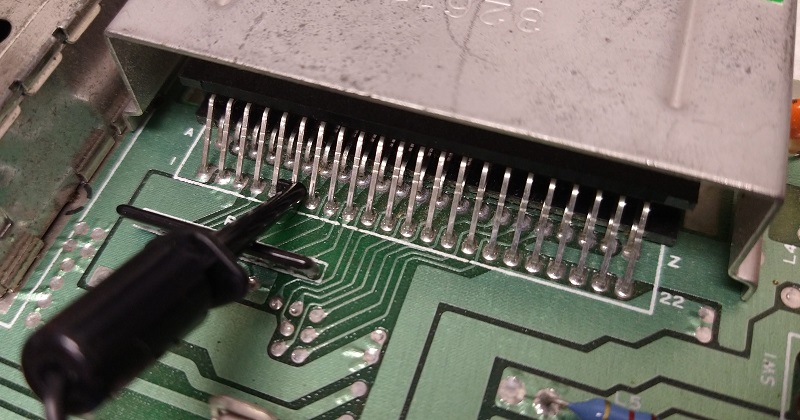
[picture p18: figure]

Or to FB18 between the Sid and Cassette port.

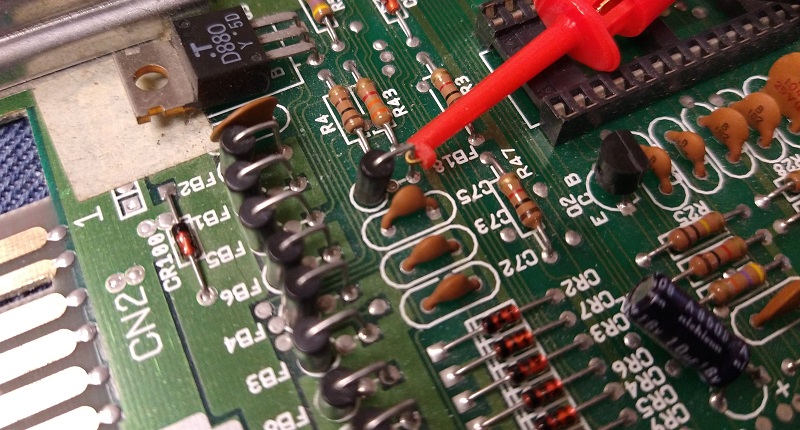
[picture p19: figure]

Now we need to pick a IO address for the Swiftlink to use.

On the cartridge port, Pin 7 = DE00, and Pin 10=DF00

Here’s an example of DE00.

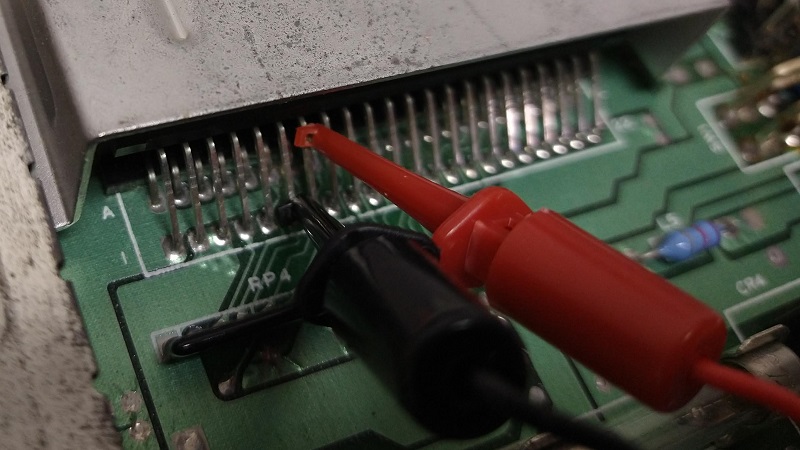
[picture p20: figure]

And here we have DF00.

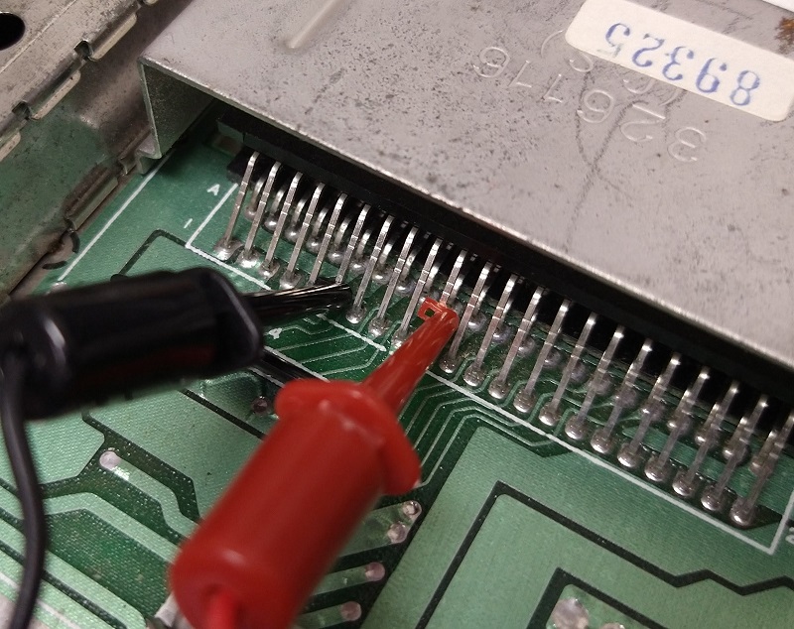
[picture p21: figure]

For D700 it’s located on u3, pin 12.

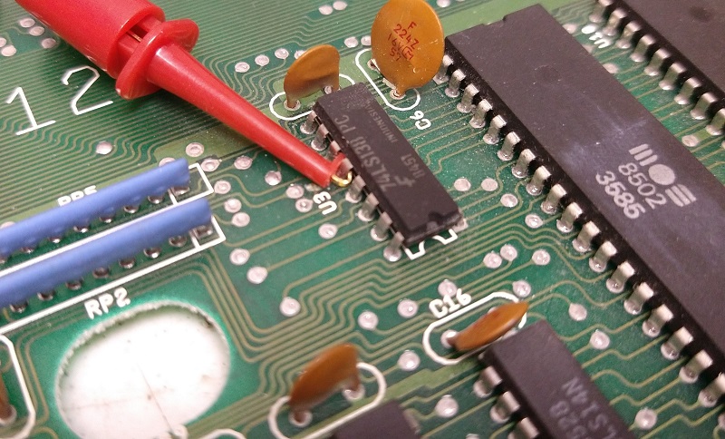
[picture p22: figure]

And that’s it, you are ready to load up your favorite terminal.

If you must have IRQ instead of NMI, you will need to remove the IRQ/NMI jumper from the Swift-L, and the run a lead (Not provided) to pin 21 of the other CIA chip. I’ve never used this, but apparently a CP/M terminal might require that.

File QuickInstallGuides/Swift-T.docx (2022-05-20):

Swift-T Quick install guide for the Commodore 64 Longboards.

Start by removing the CIA chip at U2.

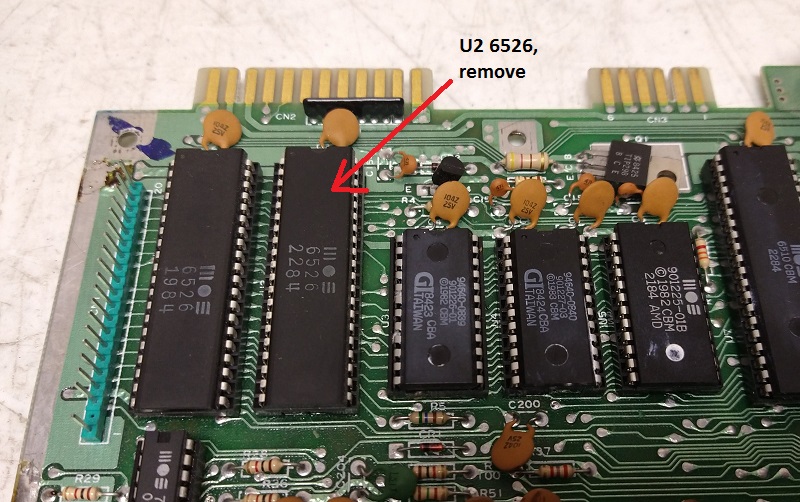
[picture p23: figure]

After removing the chip, insert the swift-t into the socket, wifi module to the rear of the machine.

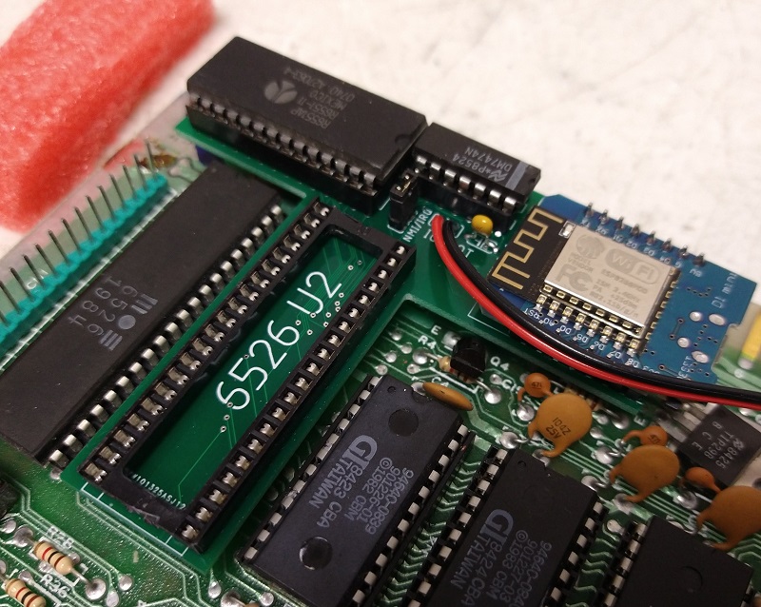
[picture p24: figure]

Next plug your original cia chip into the socket on the Swift-T. Notch goes towards the rear of the machine.

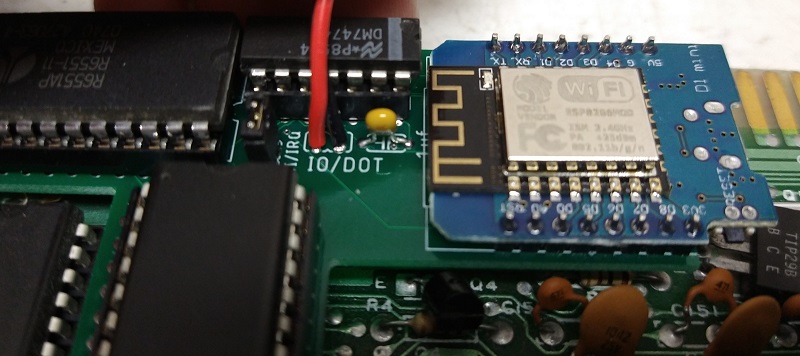
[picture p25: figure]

Now double check which wire is which. In the example, Red goes to the IO select pin, and black goes to DOT Clock.

Dot Clock ALWAYS goes to pin 6 on the cartridge port. This is the same on the 64 or the 128.


Now we need to pick a IO address for the Swiftlink Driver to use.

On the cartridge port, Pin 7 = DE00, and Pin 10=DF00

Here’s a example of DE00.


And here we have DF00.


For D700 addressing you need to remove and socket U15, this is usually located to the right of the ram chips.

Then install the option D700 adapter board, and connect the lead to the D700 header pin.

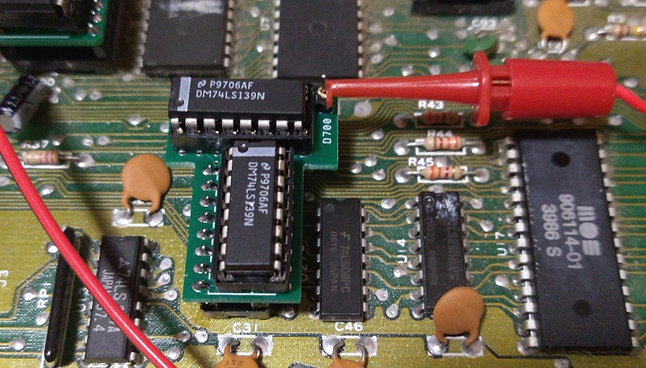
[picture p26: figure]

And that’s it, you are ready to load up your favorite terminal.

If you must have IRQ instead of NMI, you will need to remove the IRQ/NMI jumper from the Swift-T, and the run a lead (Not provided) to pin 21 of the other CIA chip.

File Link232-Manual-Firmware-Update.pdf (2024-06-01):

## Link232-Wifi Manual Firmware Update Tutorial

This will cover the manual upgrade for the Link232-Wifi using the Ardunio IDE. I’m using Windows for the Tutorial, but most of the steps will work for Mac/Linux
Hardware needed.
You will need a micro usb cable from the computer to the Wemos D1 mini in the Link232-Wifi.
Step 1. Installing CH340 drivers.

Go to the following Website.
https://learn.sparkfun.com/tutorials/how-to-install-ch340-drivers/all
And install the correct drivers for your Operating System, this will allow the Link232-Wifi appear as a serial port.
Step 2. Install Arduino IDE.

Go to the following Website.
https://www.arduino.cc/en/software
Select the correct installer for your Operating System, download and install.

## Step 3. Download Current Firmware

Download and extract the current firmware from my github page. https://github.com/dabonetn/Link232-Wifi/archive/refs/heads/master.zip

You must unzip this file to use it, under Windows explorer, right click and select extract all.

Step 4. Arduino IDE Setup.

Start Arduino, and go to Preferences then settings.
Add the following to the Additional Boards Manager URLs. https://arduino.esp8266.com/stable/package_esp8266com_index.json It should look like this.

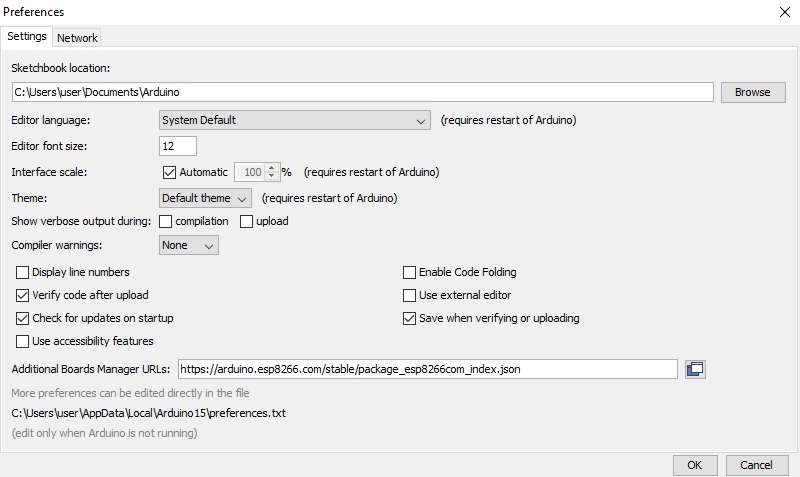
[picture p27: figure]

Now add the board.
Select Tools, Board, And Boards Manager. Type esp8266 in the search bar.

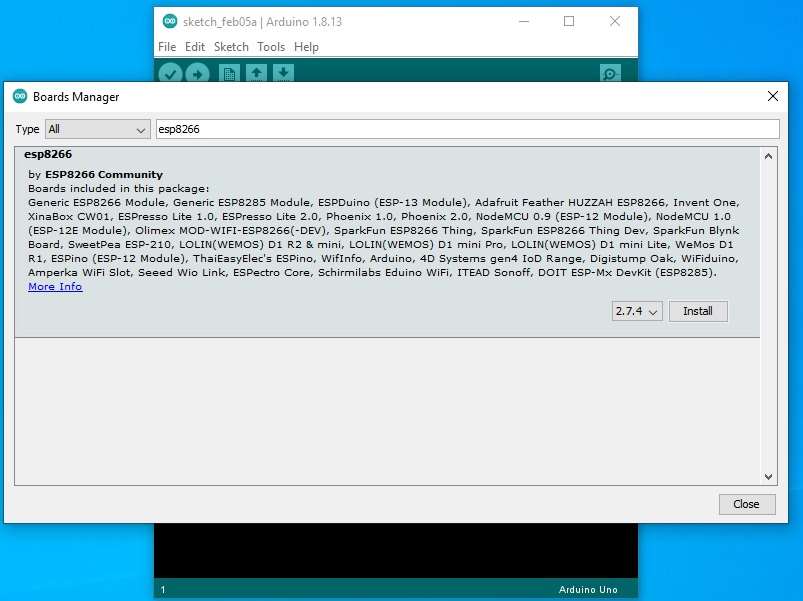
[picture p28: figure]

Choose Version 2.7.4. Other versions haven’t been tested. Click install.

## Step 5. Programming The Firmware

Load the latest firmware that you downloaded and extracted.

Select File, Open,
Navigate to: (Where you extracted)\Link232-Wifi-master\zimodem\zimodem\zimodem.ino

Now select the correct board for programming.
Go to Tools, Board, ESP8266B Boards, LOLIN(WEMOS) D1 R2 & mini

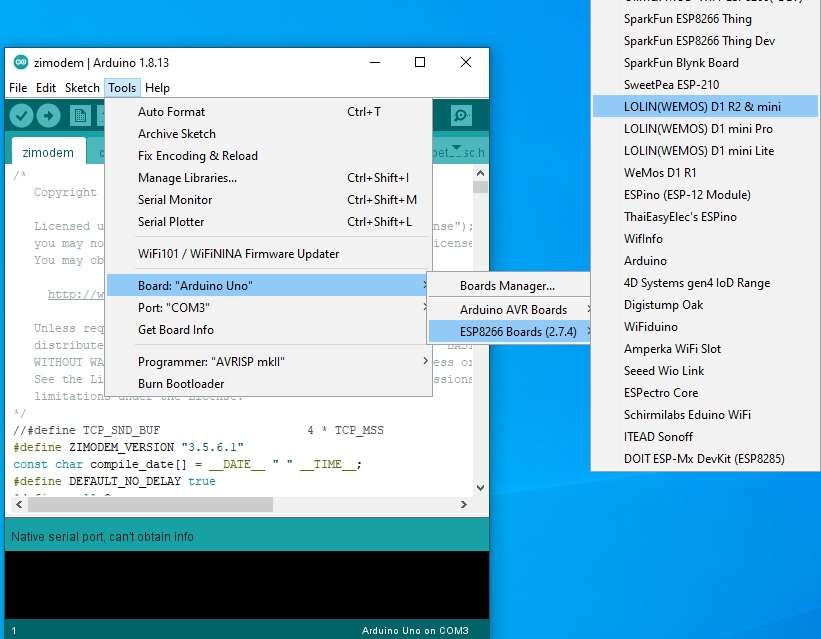
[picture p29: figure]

Now double check the board settings. Upload Speed: 921600
CPU Frequency: 80 Mhz
Flash Size: “4MB (FS:2MB OTA:~1019KB) Debug Port: Disabled
Debug Level: None
IwIP Variant: v2 Lower Memory
VTables: Flash
Exceptions: Legacy (new can return nullptr) Erase Flash: Only Sketch
SSL Support: All SSL ciphers

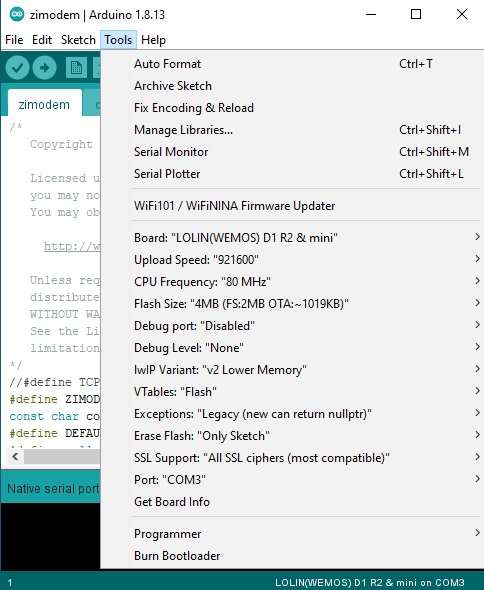
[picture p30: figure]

Remove the case of the Link232-Wifi, place it on a non-conductive surface and plug it into the computer. Do NOT have it plugged into the Commodore at this stage.

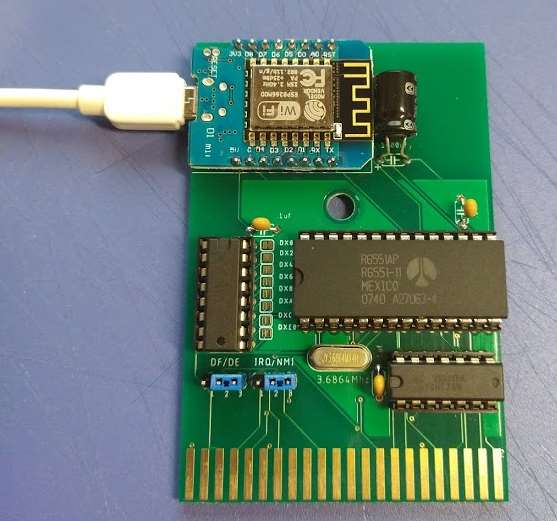
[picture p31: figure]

After you do this, windows will add the new serial port, wait until windows is done with the install. (Should be pretty quick)

Now select the correct Port for the Link232-Wifi.
Go to Tools, Port, and select the new com port.
Then check that it’s the correct port.
Go to Tools, Get Board Info. It should return the following.

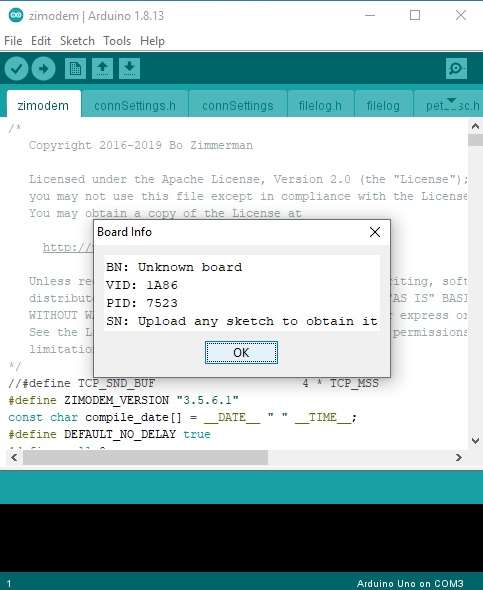
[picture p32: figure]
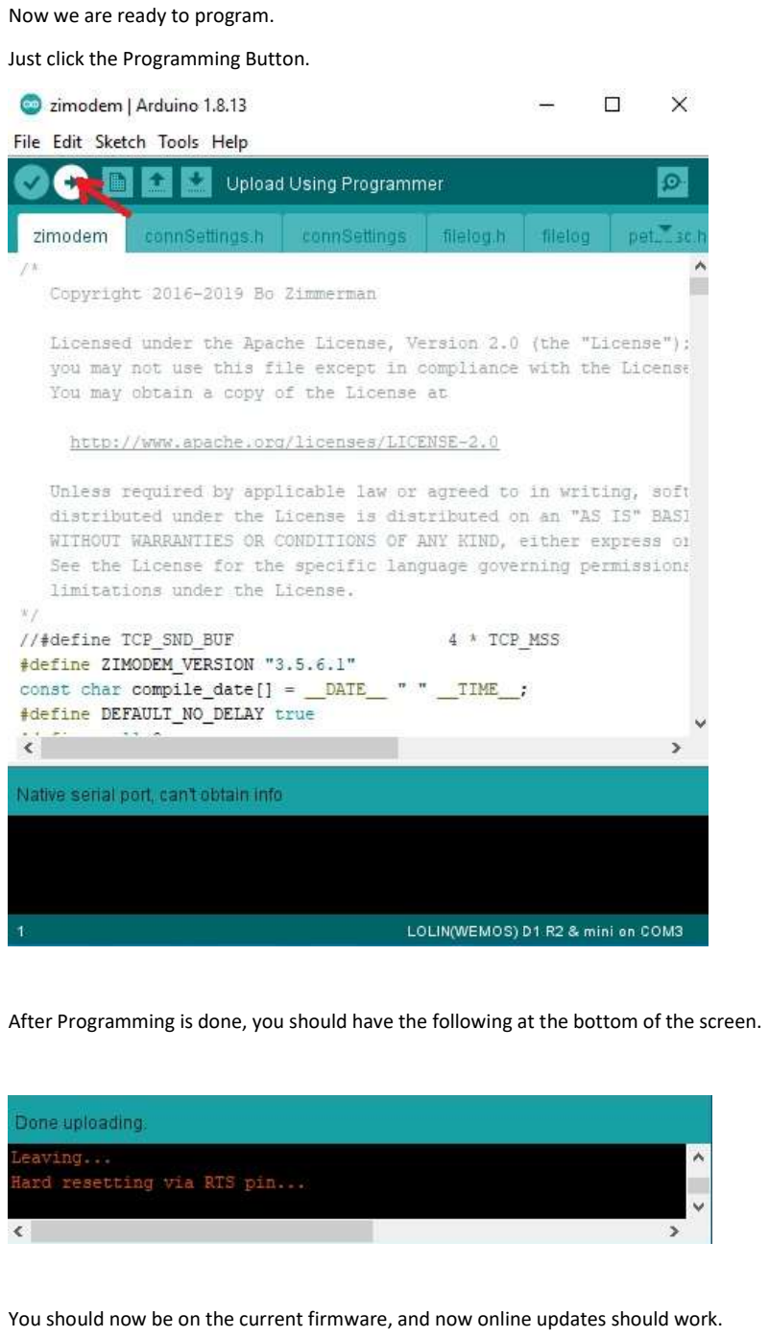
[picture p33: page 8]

Now we are ready to program. Just click the Programming Button.

After Programming is done, you should have the following at the bottom of the screen.

You should now be on the current firmware, and now online updates should work.

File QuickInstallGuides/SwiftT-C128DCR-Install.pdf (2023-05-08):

Swi-T C128DCR Installaon Instrucons.

The Swi-T Internal Swilink Compable modem installs into the U1 socket of the C128DCR. This is located near the cartridge slot. There needs to be a socket installed at this locaon.

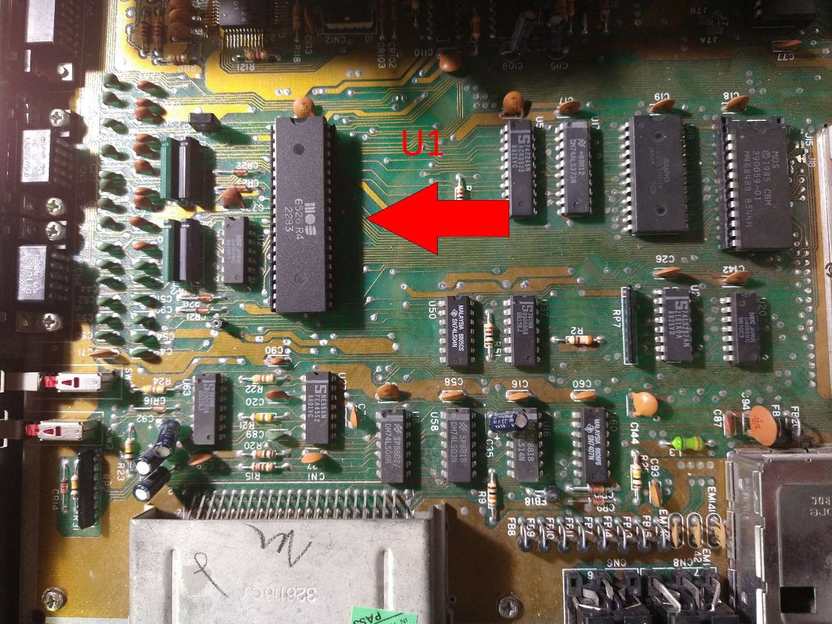
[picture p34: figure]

The next prerequisite is that the disk drive connecon is vercal, most are but some have been seen with a 90-degree connector that interferes with the modem.

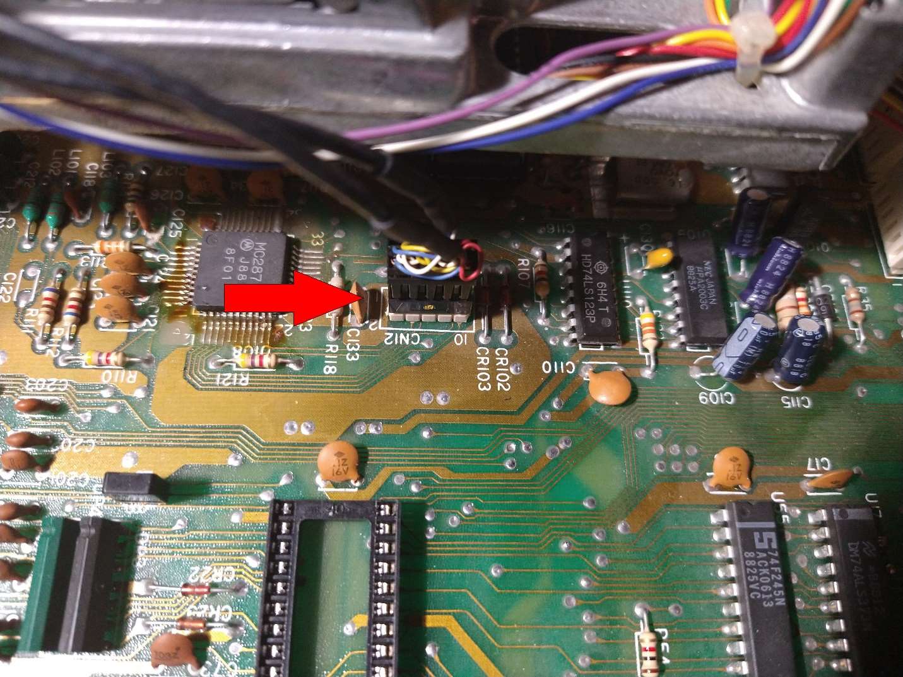
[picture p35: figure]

If your computer has a socket installed at U1 and the vercal drive connector like the above picture we are ready to install.

First remove the CIA (6526) chip located at U1.

Then install the modem with the larger poron towards the disk drive.

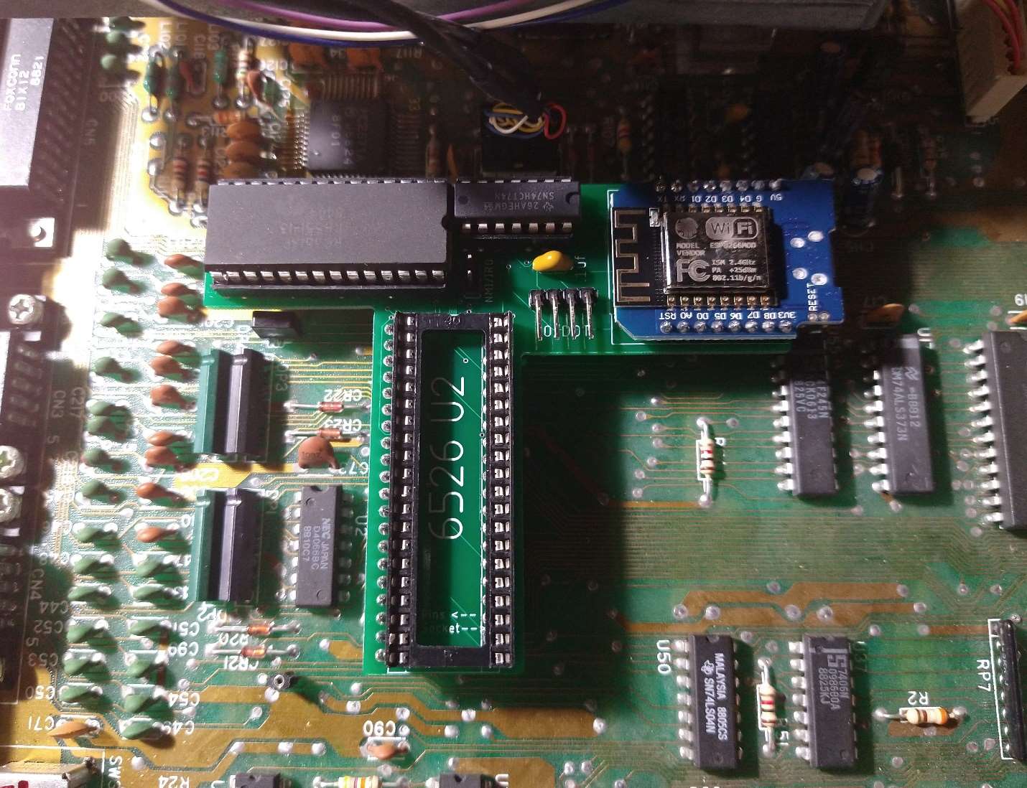
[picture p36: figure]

Then reinstall the cia into the socket on the modem. Pin 1 goes towards the disk drive. (Top le of the socket in the above picture)

There are 4 cables are included with the modem. Only 3 are used for the installaon. There are 3 short cables, and one long cable.
Any of the short cables can be used for the first 2 connecons.

First is the NMI signal. The clip goes to pin 12 of U63. Make sure that the clip is firmly on the pin and not touching any other adjacent pins.

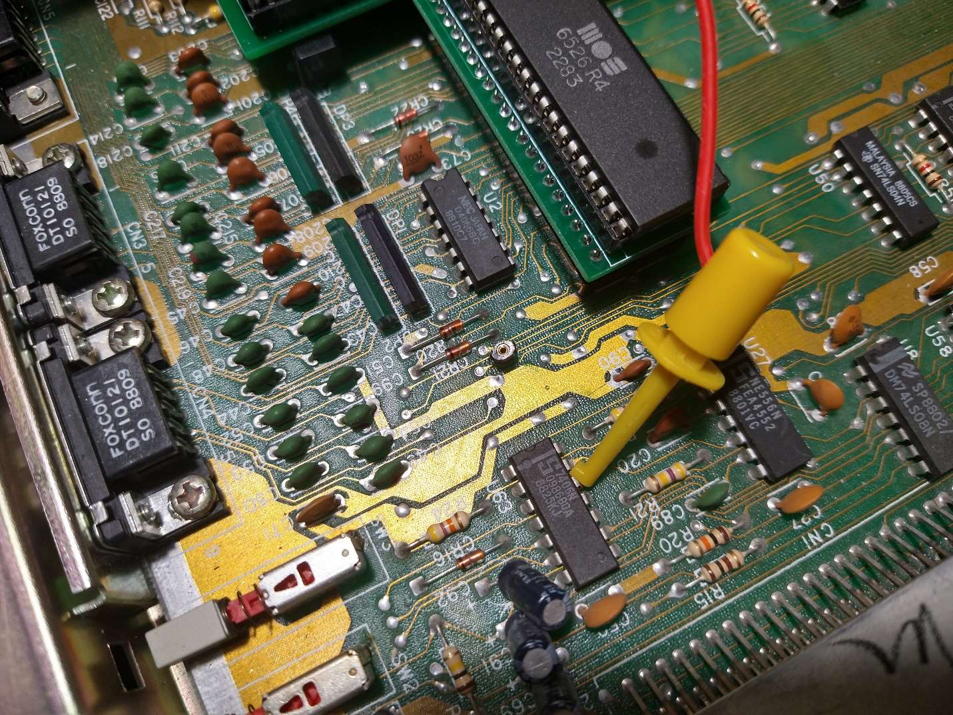
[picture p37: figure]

The other end of the NMI cable goes to the modem header labeled NMI/IRQ, and is installed on the IRQ side.

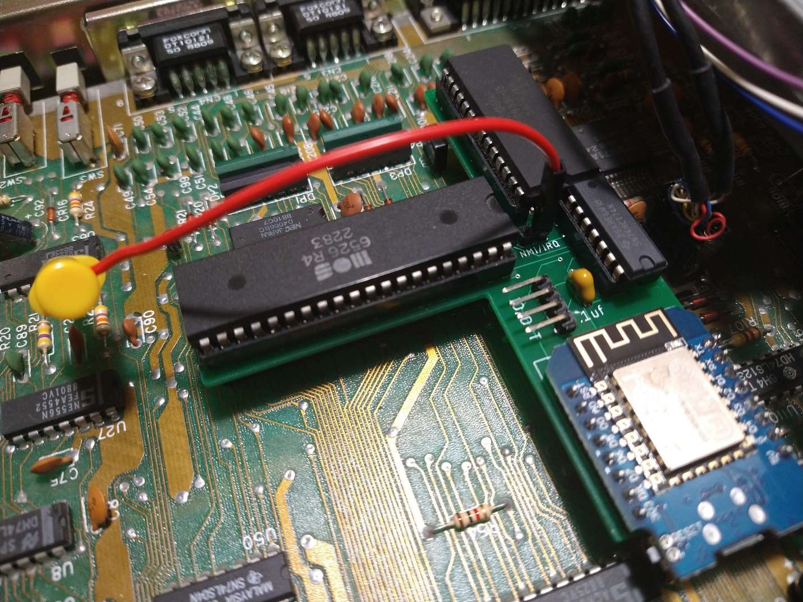
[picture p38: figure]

The Dot Clock is next. Use the clip to aach to FB18. This is a ferrite bead and has a long exposed lead.

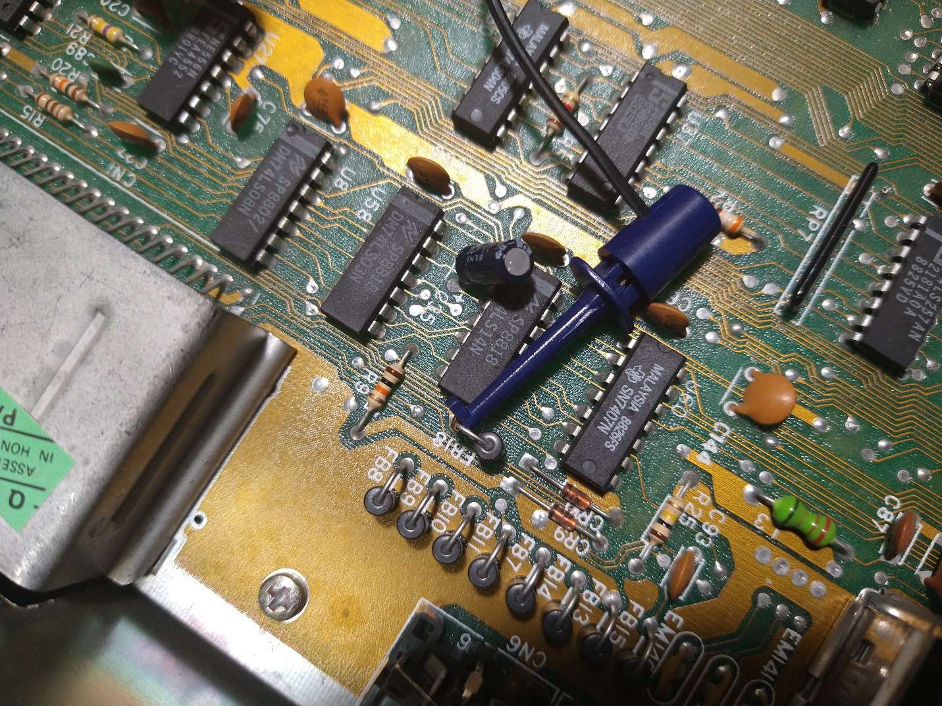
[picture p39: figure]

The other end goes to the IO/DOT header, 3rd pin from the le.

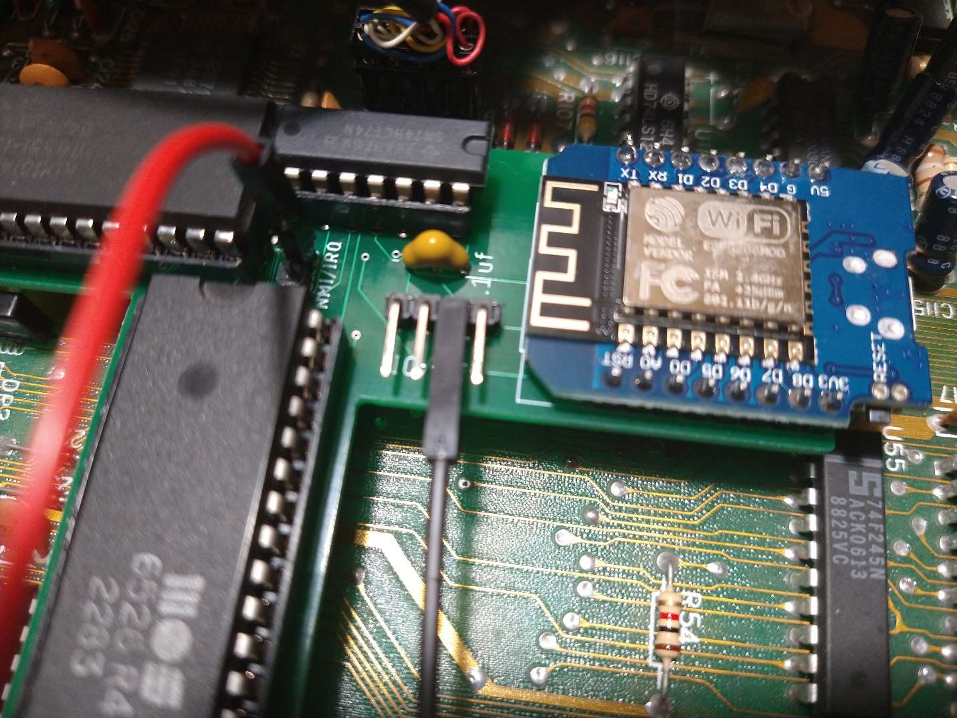
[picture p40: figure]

The last cable is for the IO address that the modem responds to.

You have 3 opons, and they have their upsides and downsides.
The original Swilink modem supported DE00 or DF00 using the cartridge port. This works with all Swilink soware, but occupies part of the cartridge address space.
This means that if you are trying to use other cartridges that use IO, you will have a conflict and they will not work.
Examples are.
Easyflash / Easyflash3 – Uses all the DE00-DF00 address space.
1700/1764/1750 REU uses DF00 - DF0F.

I imagine that the Kungfu Flash, Ultimate 1541 II+ and other style cartridges have similar requirements.

Most newer terminal / bbs software that supported Swiftlink also support the D700 IO address.

This left the cartridge port free and open for power users.

Examples of software that supports D700 addressing.

CCGMS – CCGMS Future

Desterm 3

Novaterm 9.6c

Dialogue 128

This is my recommended config for the internal modem.

It is also possible to share the D700 address with a Megabit 128 internal rom with no problems.

D700 is available at pin 12 of U3. This chip is located near the front of the machine, obscured by the power supply, slightly above the U36 open socket.

Use the provided long cable to attach to the pin, making sure it’s correctly seated, and not shorting any adjacent pins.

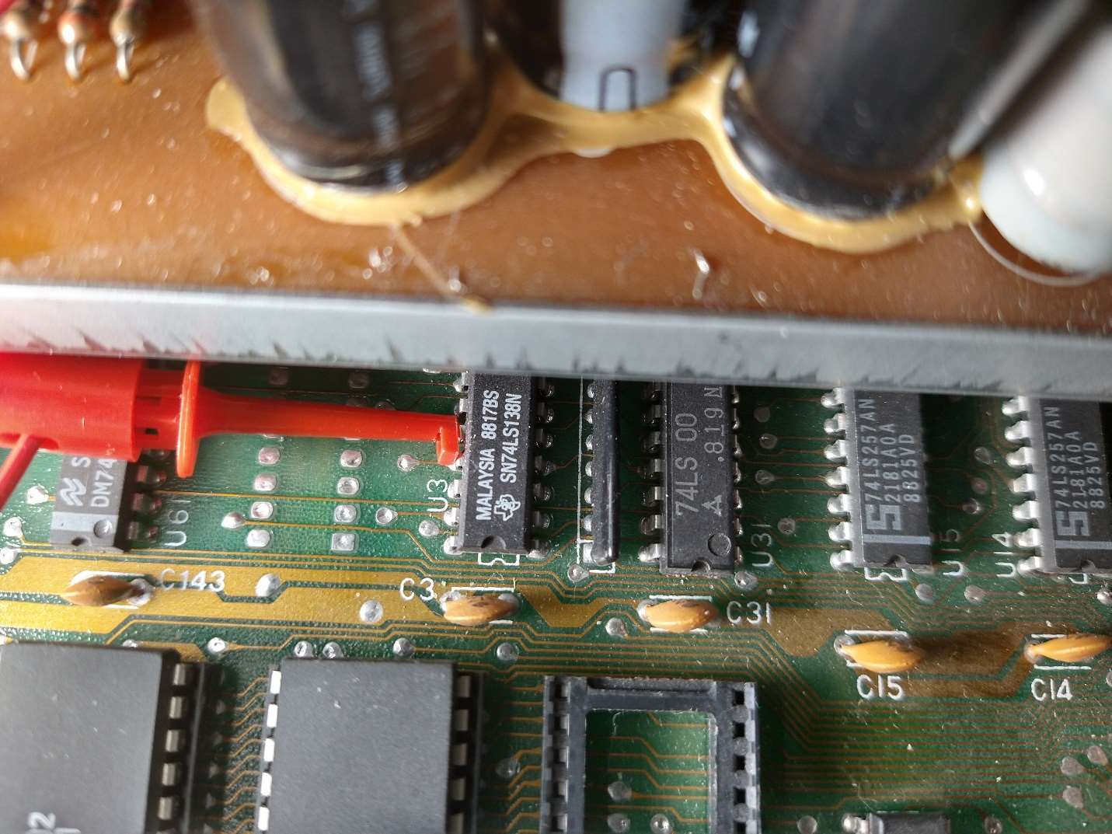
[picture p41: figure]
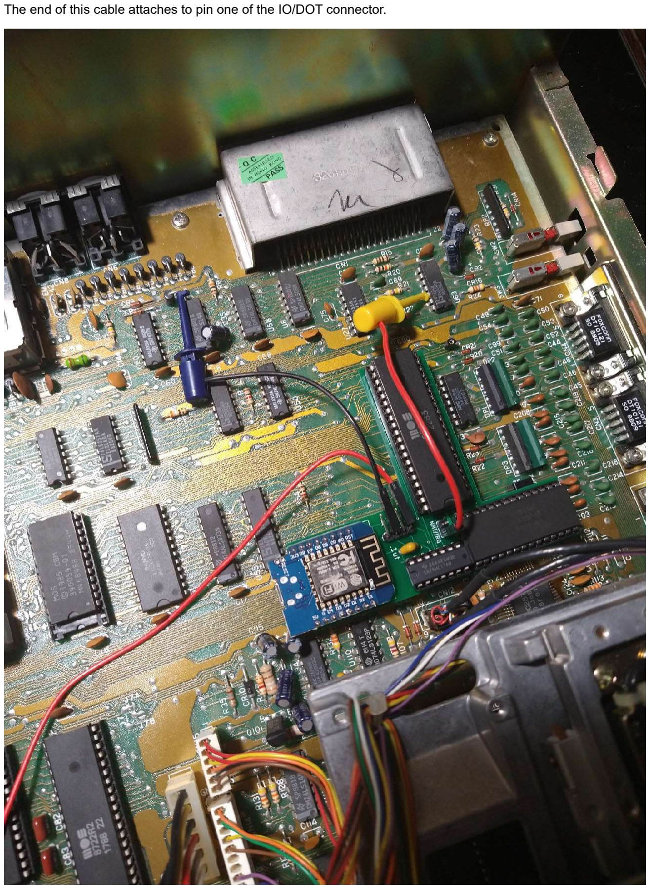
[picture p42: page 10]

The end of this cable attaches to pin one of the IO/DOT connector.

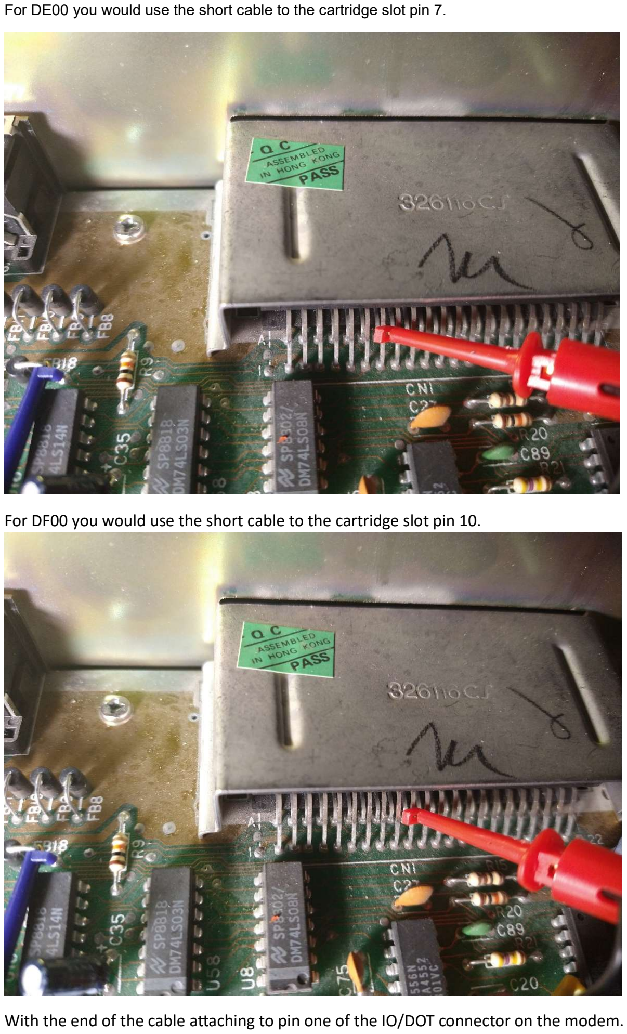
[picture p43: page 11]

For DE00 you would use the short cable to the cartridge slot pin 7.

For DF00 you would use the short cable to the cartridge slot pin 10.

With the end of the cable aaching to pin one of the IO/DOT connector on the modem.

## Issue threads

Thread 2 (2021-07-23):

"Link232-Wifi-cartridge-bottom.stl" does not match top half of the case.

hackup, 2021-07-23:
Thanks for sharing this nice project!

I just noticed a minor issue: The "Link232-Wifi-cartridge-bottom.stl" model does not seem to match the top half of the case. It seems to short and the center hole is in the wrong position. The "Number4screw" variant on the other hand looks fine. I would suggest to either fix the model or to remove it from the repo.

dabonetn, 2021-11-23:
Thanks, I'm just now noticing the open issues, I never got a email.
Deleting the wrong model now.

Closed 2021-11-23.

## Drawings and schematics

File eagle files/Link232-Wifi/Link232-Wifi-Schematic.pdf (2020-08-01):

# 22 ABCDEFHJKLMNPRSTUVWXYZ

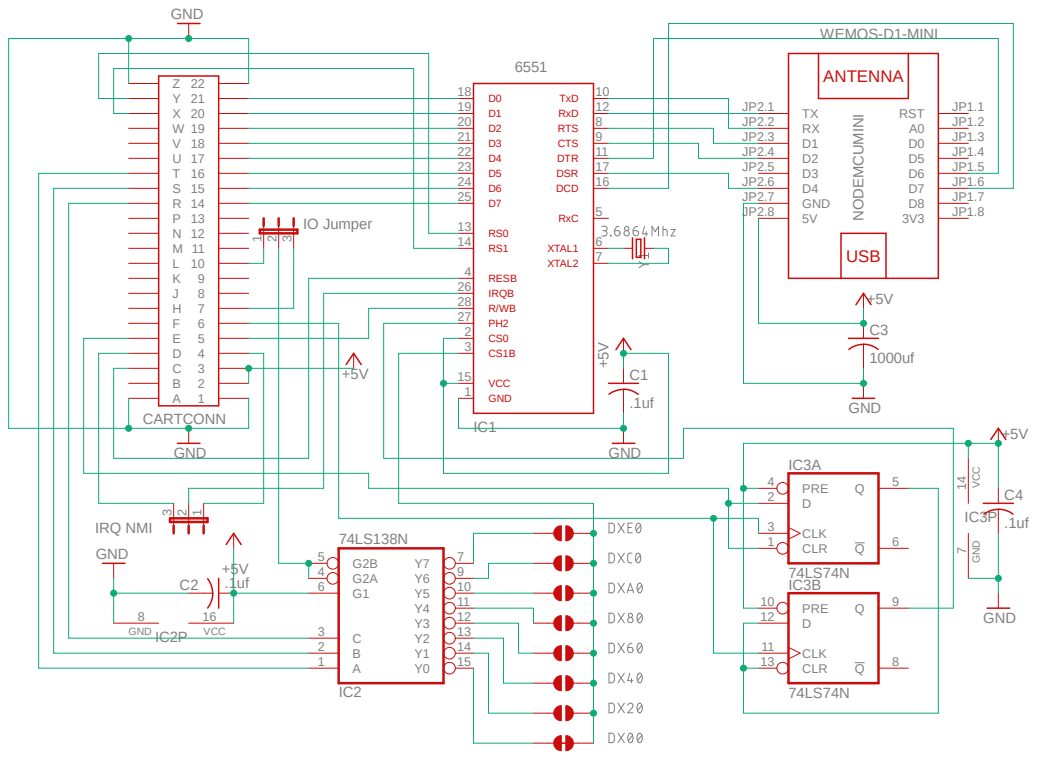
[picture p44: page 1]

TX JP2.1 | ANTENNA | A0 D0 D5

19 | 12
20 | | | RX JP2.2 | JP1.2
21 | | | D1 JP2.3 | JP1.3
22 | 11 | | D2 JP2.4 | JP1.4
23 | 17 | | D3 JP2.5
24 | 16 | D4 JP2.6

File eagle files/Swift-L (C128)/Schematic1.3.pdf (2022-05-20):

PA7 9 | PA6 8 | PA5 7 | PA4 6 | PA3 5 | PA2 4 | PA1 3 | PA0 2
D7 | 26 D6 | 27 D5 | 28 D4 | 29 D3 | 30 D2 | 31 D1 | 32 D0 | 33

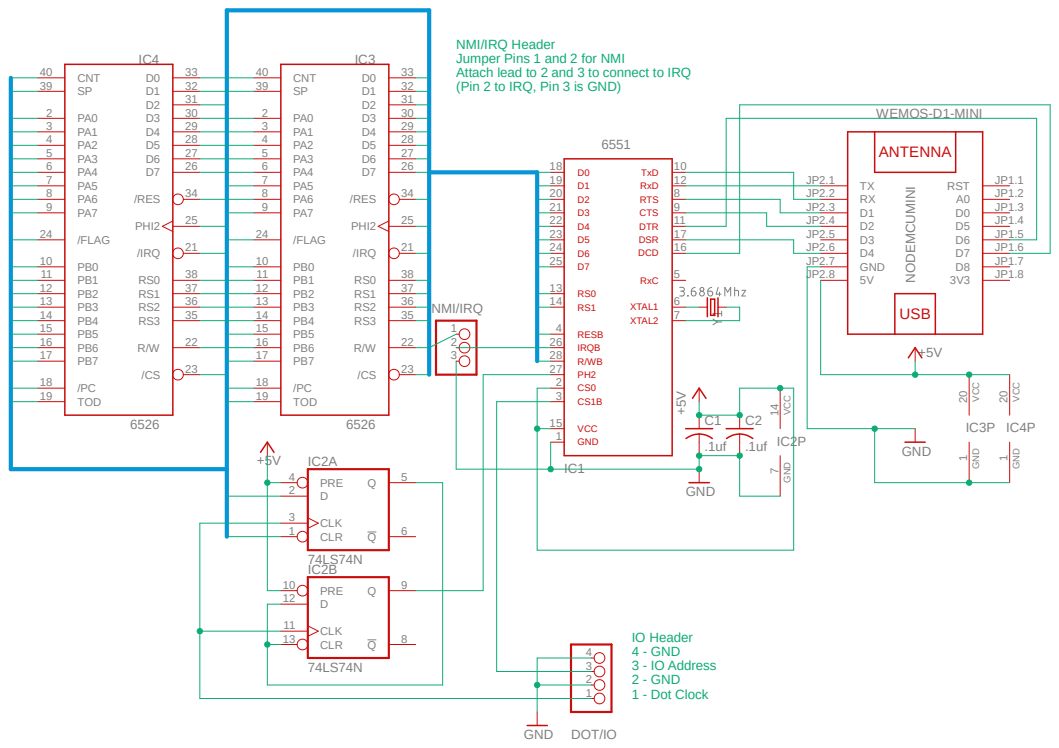
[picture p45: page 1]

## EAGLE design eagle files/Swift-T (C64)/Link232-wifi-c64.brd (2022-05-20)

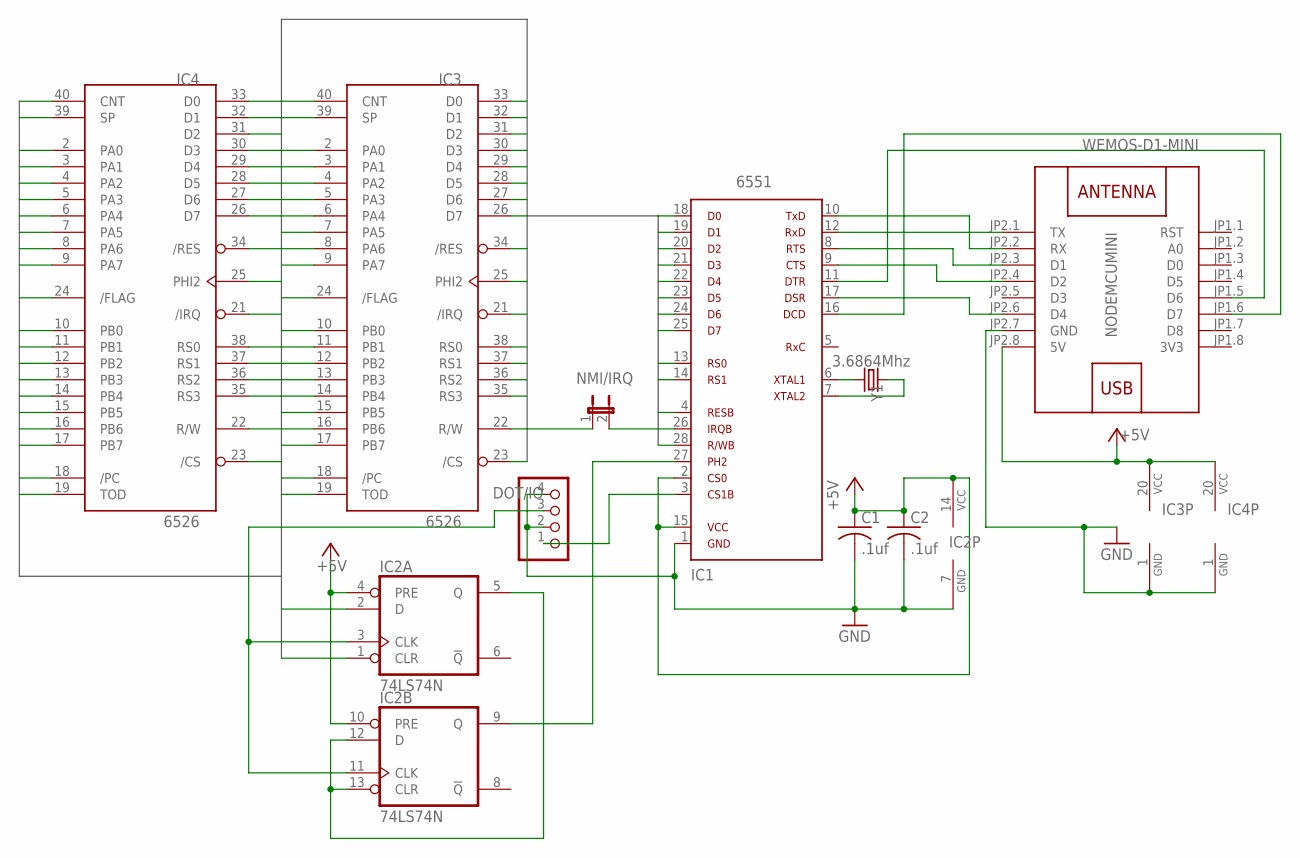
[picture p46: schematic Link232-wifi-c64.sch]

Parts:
C1, C2: .1uf; C050-024X044
IC1: 6551
IC2: 74LS74N; DIL14
IC3, IC4: 6526; DIP40
JP1: NMI/IRQ; JP1
JP2: DOT/IO; 1X04
NODEMCUMINI: WEMOS-D1-MINI
Y1: 3.6864Mhz; HC49US

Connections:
3V3: NODEMCUMINI.JP1.8 (3V3)
+5V: C1.1, C2.1, IC1.2, IC1.15, IC2.4 (PRE), IC2.10 (PRE), IC2.14 (VCC), IC3.20 (VCC), IC4.20 (VCC), NODEMCUMINI.JP2.8 (5V)
/CS: IC3.23 (/CS), IC4.23 (/CS)
/FLAG: IC3.24 (/FLAG), IC4.24 (/FLAG)
/PC: IC3.18 (/PC), IC4.18 (/PC)
CNT: IC3.40 (CNT), IC4.40 (CNT)
D0: IC1.18, IC3.33 (D0), IC4.33 (D0)
D1: IC1.19, IC3.32 (D1), IC4.32 (D1)
D2: IC1.20, IC3.31 (D2), IC4.31 (D2)
D3: IC1.21, IC3.30 (D3), IC4.30 (D3)
D4: IC1.22, IC3.29 (D4), IC4.29 (D4)
D5: IC1.23, IC3.28 (D5), IC4.28 (D5)
D6: IC1.24, IC3.27 (D6), IC4.27 (D6)
D7: IC1.25, IC3.26 (D7), IC4.26 (D7)
GND: C1.2, C2.2, IC1.1, IC2.7 (GND), IC3.1 (GND), IC4.1 (GND), JP2.2, JP2.4, NODEMCUMINI.JP2.7 (GND)
IRQ: IC3.21 (/IRQ), IC4.21 (/IRQ), JP1.1
unnamed: IC2.3 (CLK), IC2.11 (CLK), JP2.3
unnamed: IC2.5 (Q), IC2.12 (D), IC2.13 (CLR)
unnamed: IC1.27, IC2.9 (Q)
unnamed: IC1.26, JP1.2
unnamed: IC1.3, JP2.1
unnamed: IC1.6, Y1.2
unnamed: IC1.7, Y1.1
unnamed: IC1.12, NODEMCUMINI.JP2.1 (TX)
unnamed: IC1.10, NODEMCUMINI.JP2.2 (RX)
unnamed: IC1.8, NODEMCUMINI.JP2.3 (D1)
unnamed: IC1.9, NODEMCUMINI.JP2.4 (D2)
unnamed: IC1.17, NODEMCUMINI.JP2.6 (D4)
unnamed: IC1.11, NODEMCUMINI.JP1.5 (D6)
unnamed: IC1.16, NODEMCUMINI.JP1.6 (D7)
PA0: IC3.2 (PA0), IC4.2 (PA0)
PA1: IC3.3 (PA1), IC4.3 (PA1)
PA2: IC3.4 (PA2), IC4.4 (PA2)
PA3: IC3.5 (PA3), IC4.5 (PA3)
PA4: IC3.6 (PA4), IC4.6 (PA4)
PA5: IC3.7 (PA5), IC4.7 (PA5)
PA6: IC3.8 (PA6), IC4.8 (PA6)
PA7: IC3.9 (PA7), IC4.9 (PA7)
PB0: IC3.10 (PB0), IC4.10 (PB0)
PB1: IC3.11 (PB1), IC4.11 (PB1)
PB2: IC3.12 (PB2), IC4.12 (PB2)
PB3: IC3.13 (PB3), IC4.13 (PB3)
PB4: IC3.14 (PB4), IC4.14 (PB4)
PB5: IC3.15 (PB5), IC4.15 (PB5)
PB6: IC3.16 (PB6), IC4.16 (PB6)
PB7: IC3.17 (PB7), IC4.17 (PB7)
PHI2: IC2.1 (CLR), IC2.2 (D), IC3.25 (PHI2), IC4.25 (PHI2)
RES: IC1.4, IC3.34 (/RES), IC4.34 (/RES)
RS0: IC1.13, IC3.38 (RS0), IC4.38 (RS0)
RS1: IC1.14, IC3.37 (RS1), IC4.37 (RS1)
RS2: IC3.36 (RS2), IC4.36 (RS2)
RS3: IC3.35 (RS3), IC4.35 (RS3)
RW: IC1.28, IC3.22 (R/W), IC4.22 (R/W)
SP: IC3.39 (SP), IC4.39 (SP)
TOD: IC3.19 (TOD), IC4.19 (TOD)

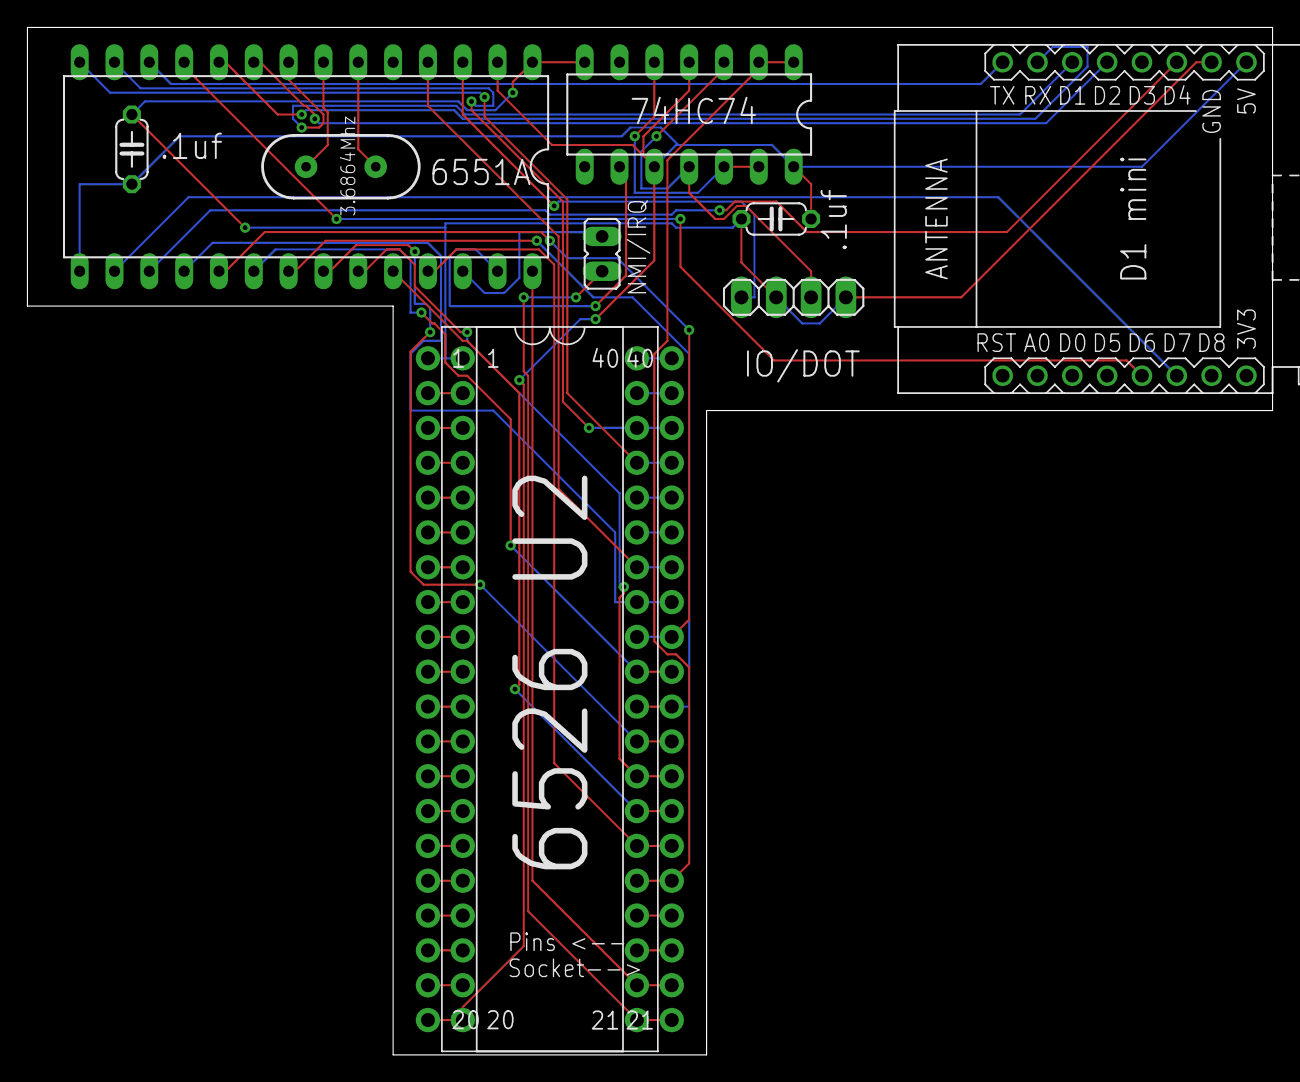
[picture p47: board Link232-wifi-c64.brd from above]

Board: 2 copper layers, 90.8 x 74.9 mm, 10 parts (0 on the bottom side), 54 nets.

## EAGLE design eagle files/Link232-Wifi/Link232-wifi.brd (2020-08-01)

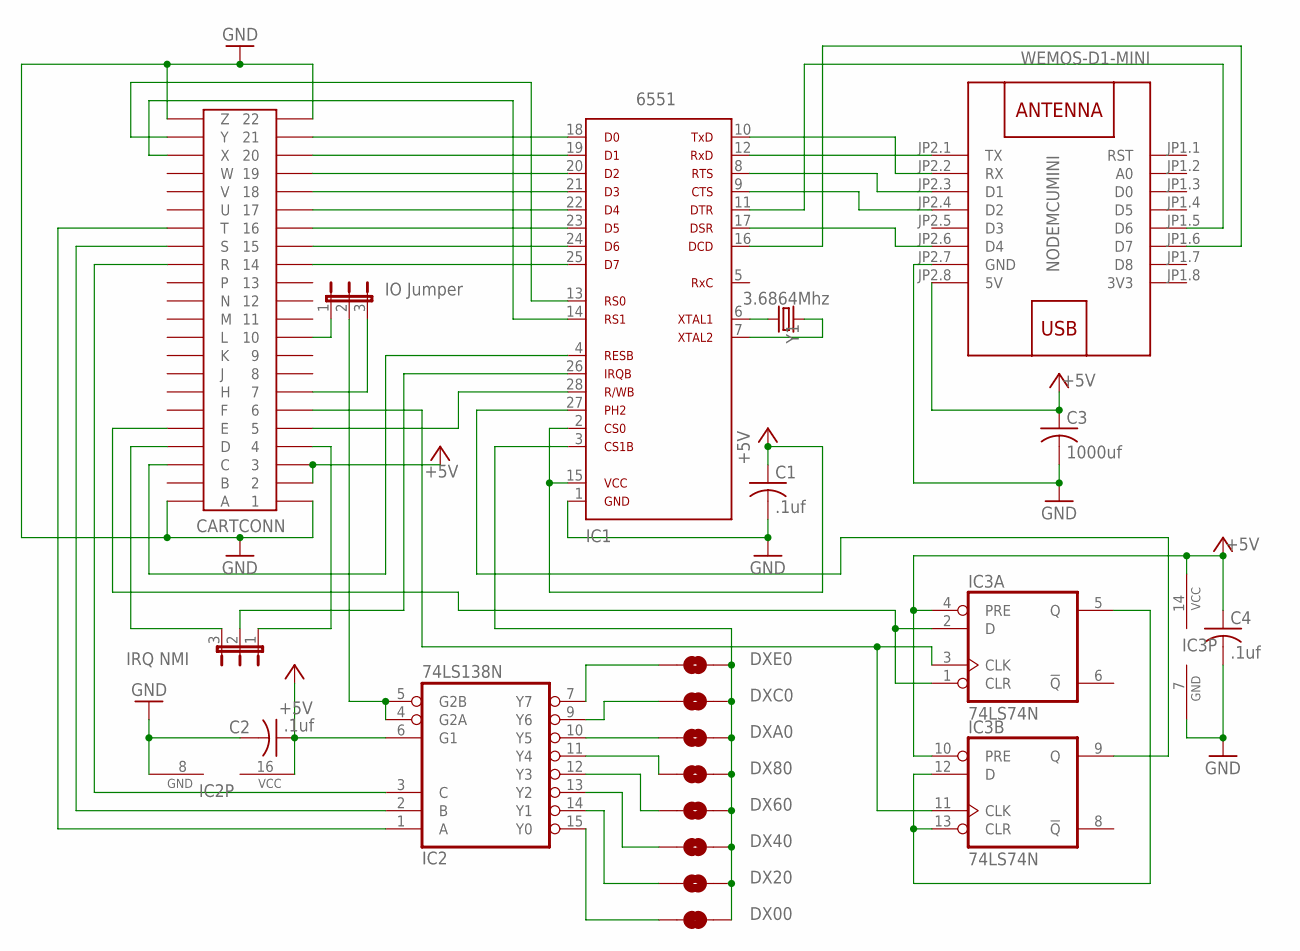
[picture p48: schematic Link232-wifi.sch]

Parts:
C1, C2, C4: .1uf; C050-024X044
C3: 1000uf; C050-024X044
CARTCONN: 44PINEDGE
DF/DE: IO Jumper; JP2
DX00: JUMPER-SMT_2_NC_TRACE_SILK; SMT-JUMPER_2_NC_TRACE_SILK
DX20, DX40, DX60, DX80: JUMPER-SMT_2_NO_SILK; SMT-JUMPER_2_NO_SILK
DXA0: JUMPER-SMT_2_NO_SILK; SMT-JUMPER_2_NO_SILK
DXC0: JUMPER-SMT_2_NO_SILK; SMT-JUMPER_2_NO_SILK
DXE0: JUMPER-SMT_2_NO_SILK; SMT-JUMPER_2_NO_SILK
IC1: 6551A; 6551
IC2: 74LS138N; DIL16
IC3: 74LS74N; DIL14
IRQ/NMI: IRQ NMI; JP2
NODEMCUMINI: WEMOS-D1-MINI
Y1: 3.6864Mhz; HC49US

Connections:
3V3: NODEMCUMINI.JP1.8 (3V3)
+5V: C1.1, C2.1, C3.1, C4.1, CARTCONN.2, CARTCONN.3, IC1.2, IC1.15, IC2.6 (G1), IC2.16 (VCC), IC3.4 (PRE), IC3.10 (PRE), IC3.14 (VCC), NODEMCUMINI.JP2.8 (5V)
GND: C1.2, C2.2, C3.2, C4.2, CARTCONN.1, CARTCONN.22, CARTCONN.A, CARTCONN.Z, IC1.1, IC2.8 (GND), IC3.7 (GND), NODEMCUMINI.JP2.7 (GND)
unnamed: CARTCONN.6, IC3.3 (CLK), IC3.11 (CLK)
unnamed: IC3.5 (Q), IC3.12 (D), IC3.13 (CLR)
unnamed: IC1.27, IC3.9 (Q)
unnamed: CARTCONN.21, IC1.18
unnamed: CARTCONN.20, IC1.19
unnamed: CARTCONN.19, IC1.20
unnamed: CARTCONN.18, IC1.21
unnamed: CARTCONN.17, IC1.22
unnamed: IC1.6, Y1.2
unnamed: IC1.7, Y1.1
unnamed: IC1.12, NODEMCUMINI.JP2.1 (TX)
unnamed: IC1.10, NODEMCUMINI.JP2.2 (RX)
unnamed: IC1.8, NODEMCUMINI.JP2.3 (D1)
unnamed: IC1.9, NODEMCUMINI.JP2.4 (D2)
unnamed: IC1.17, NODEMCUMINI.JP2.6 (D4)
unnamed: IC1.11, NODEMCUMINI.JP1.5 (D6)
unnamed: IC1.16, NODEMCUMINI.JP1.6 (D7)
unnamed: CARTCONN.5, IC1.28
unnamed: CARTCONN.C, IC1.4
unnamed: CARTCONN.D, IRQ/NMI.3
unnamed: CARTCONN.E, IC3.1 (CLR), IC3.2 (D)
unnamed: CARTCONN.10, DF/DE.1
unnamed: CARTCONN.7, DF/DE.3
unnamed: DF/DE.2, IC2.4 (G2A), IC2.5 (G2B)
unnamed: CARTCONN.T, IC2.1 (A)
unnamed: CARTCONN.S, IC2.2 (B)
unnamed: CARTCONN.R, IC2.3 (C)
unnamed: CARTCONN.X, IC1.14
unnamed: CARTCONN.Y, IC1.13
unnamed: DXE0.1, IC2.7 (Y7)
unnamed: CARTCONN.4, IRQ/NMI.1
unnamed: DXC0.1, IC2.9 (Y6)
unnamed: DXA0.1, IC2.10 (Y5)
unnamed: DX80.1, IC2.11 (Y4)
unnamed: DX60.1, IC2.12 (Y3)
unnamed: DX40.1, IC2.13 (Y2)
unnamed: DX20.1, IC2.14 (Y1)
unnamed: DX00.1, IC2.15 (Y0)
unnamed: DX00.2, DX20.2, DX40.2, DX60.2, DX80.2, DXA0.2, DXC0.2, DXE0.2, IC1.3
unnamed: CARTCONN.16, IC1.23
unnamed: IC1.26, IRQ/NMI.2
unnamed: CARTCONN.15, IC1.24
unnamed: CARTCONN.14, IC1.25

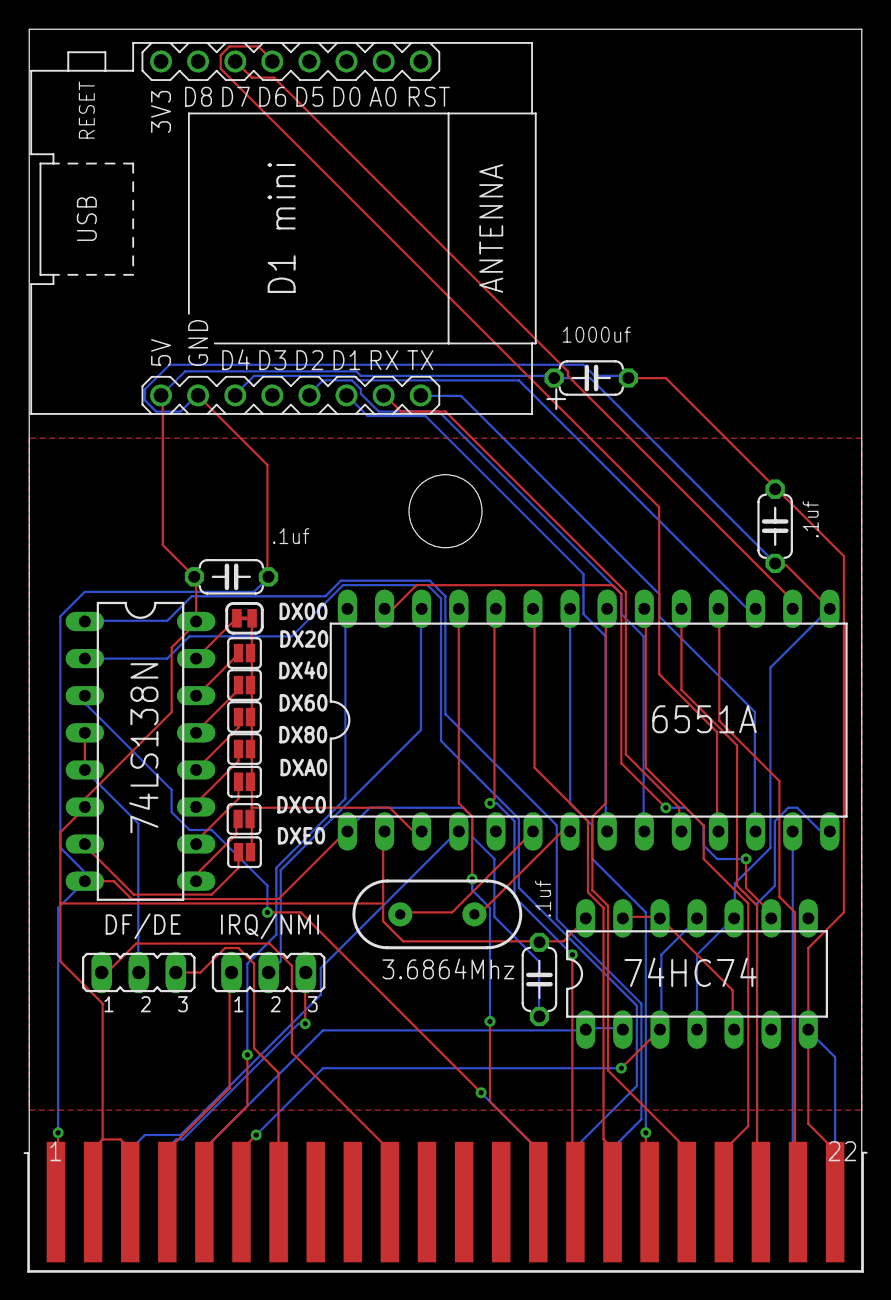
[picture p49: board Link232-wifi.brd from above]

Board: 2 copper layers, 57.0 x 85.0 mm, 20 parts (0 on the bottom side), 45 nets.

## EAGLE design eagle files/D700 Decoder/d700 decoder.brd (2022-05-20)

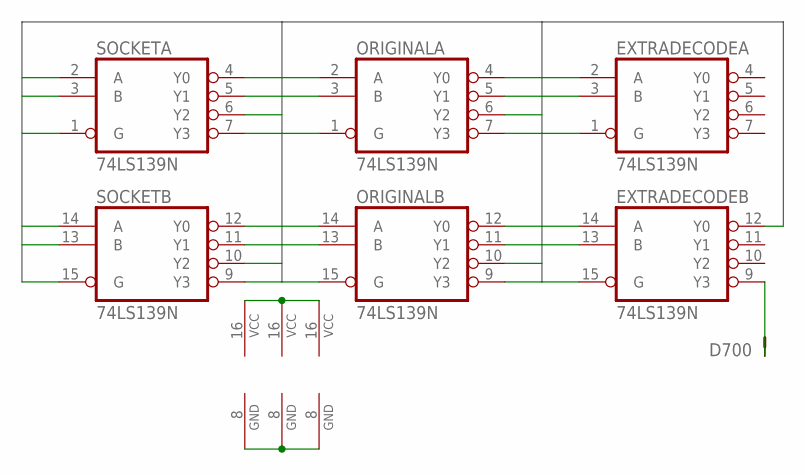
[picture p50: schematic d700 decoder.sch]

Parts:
D700: TP; JP1
EXTRADECODE: 74LS139N; DIL16
ORIGINAL: 74LS139N; DIL16
SOCKET: 74LS139N; DIL16

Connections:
A(2): EXTRADECODE.2 (A), ORIGINAL.2 (A), SOCKET.2 (A)
A(14): EXTRADECODE.14 (A), ORIGINAL.14 (A), SOCKET.14 (A)
B(3): EXTRADECODE.3 (B), ORIGINAL.3 (B), SOCKET.3 (B)
B(13): EXTRADECODE.13 (B), ORIGINAL.13 (B), SOCKET.13 (B)
G(1): EXTRADECODE.1 (G), ORIGINAL.1 (G), SOCKET.1 (G)
G(15): ORIGINAL.15 (G), SOCKET.15 (G)
GND: EXTRADECODE.8 (GND), ORIGINAL.8 (GND), SOCKET.8 (GND)
unnamed: D700.1, EXTRADECODE.9 (Y3)
SIDINTERNAL: EXTRADECODE.15 (G), ORIGINAL.5 (Y1)
VCC: EXTRADECODE.16 (VCC), ORIGINAL.16 (VCC), SOCKET.16 (VCC)
Y0(4-VICOUT): ORIGINAL.4 (Y0), SOCKET.4 (Y0)
Y0(12): ORIGINAL.12 (Y0), SOCKET.12 (Y0)
Y1(5-SIDOUT): EXTRADECODE.12 (Y0), SOCKET.5 (Y1)
Y1(11): ORIGINAL.11 (Y1), SOCKET.11 (Y1)
Y2(6): ORIGINAL.6 (Y2), SOCKET.6 (Y2)
Y2(10): ORIGINAL.10 (Y2), SOCKET.10 (Y2)
Y3(7): ORIGINAL.7 (Y3), SOCKET.7 (Y3)
Y3(9): ORIGINAL.9 (Y3), SOCKET.9 (Y3)

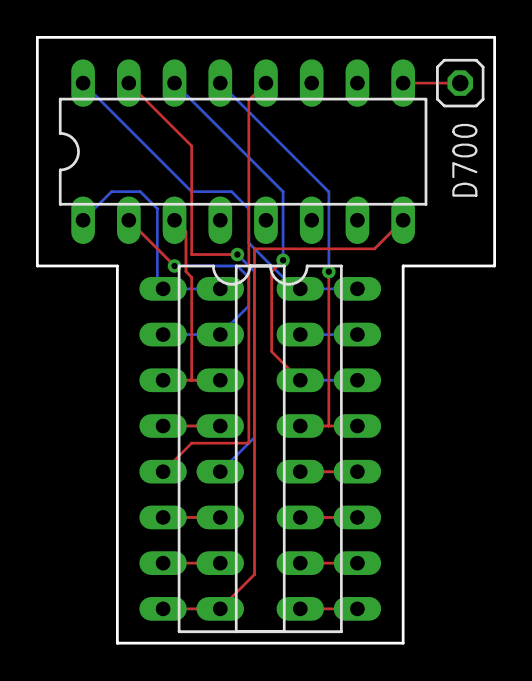
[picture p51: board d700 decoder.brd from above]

Board: 2 copper layers, 25.4 x 33.7 mm, 4 parts (0 on the bottom side), 18 nets.

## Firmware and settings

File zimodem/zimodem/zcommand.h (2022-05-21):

/*
   Copyright 2016-2019 Bo Zimmerman

   Licensed under the Apache License, Version 2.0 (the "License");
   you may not use this file except in compliance with the License.
   You may obtain a copy of the License at

	   http://www.apache.org/licenses/LICENSE-2.0

   Unless required by applicable law or agreed to in writing, software
   distributed under the License is distributed on an "AS IS" BASIS,
   WITHOUT WARRANTIES OR CONDITIONS OF ANY KIND, either express or implied.
   See the License for the specific language governing permissions and
   limitations under the License.
*/

const int MAX_COMMAND_SIZE=256;
static const char *CONFIG_FILE_OLD = "/zconfig.txt";
static const char *CONFIG_FILE     = "/zconfig_v2.txt";
#define ZI_STATE_MACHINE_LEN 7
#define DEFAULT_TERMTYPE "Zimodem"
#define DEFAULT_BUSYMSG "\r\nBUSY\r\n7\r\n"

enum ZResult
{
  ZOK,
  ZERROR,
  ZCONNECT,
  ZNOCARRIER,
  ZNOANSWER,
  ZIGNORE,
  ZIGNORE_SPECIAL
};

enum ConfigOptions
{
  CFG_WIFISSI=0,
  CFG_WIFIPW=1,
  CFG_BAUDRATE=2,
  CFG_EOLN=3,
  CFG_FLOWCONTROL=4,
  CFG_ECHO=5,
  CFG_RESP_SUPP=6,
  CFG_RESP_NUM=7,
  CFG_RESP_LONG=8,
  CFG_PETSCIIMODE=9,
  CFG_DCDMODE=10,
  CFG_UART=11,
  CFG_CTSMODE=12,
  CFG_RTSMODE=13,
  CFG_DCDPIN=14,
  CFG_CTSPIN=15,
  CFG_RTSPIN=16,
  CFG_S0_RINGS=17,
  CFG_S41_STREAM=18,
  CFG_S60_LISTEN=19,
  CFG_RIMODE=20,
  CFG_DTRMODE=21,
  CFG_DSRMODE=22,
  CFG_RIPIN=23,
  CFG_DTRPIN=24,
  CFG_DSRPIN=25,
  CFG_TIMEZONE=26,
  CFG_TIMEFMT=27,
  CFG_TIMEURL=28,
  CFG_HOSTNAME=29,
  CFG_PRINTDELAYMS=30,
  CFG_PRINTSPEC=31,
  CFG_TERMTYPE=32,
  CFG_STATIC_IP=33,
  CFG_STATIC_DNS=34,
  CFG_STATIC_GW=35,
  CFG_STATIC_SN=36,
  CFG_BUSYMSG=37,
  CFG_S62_TELNET=38,
  CFG_LAST=38
};

const ConfigOptions v2HexCfgs[] = { CFG_WIFISSI, CFG_WIFIPW, CFG_TIMEZONE, CFG_TIMEFMT, CFG_TIMEURL,
    CFG_PRINTSPEC, CFG_BUSYMSG, CFG_HOSTNAME, CFG_TERMTYPE, (ConfigOptions)255 };

enum BinType
{
  BTYPE_NORMAL=0,
  BTYPE_HEX=1,
  BTYPE_DEC=2,
  BTYPE_NORMAL_NOCHK=3,
  BTYPE_INVALID=4
};

class ZCommand : public ZMode
{
  friend class WiFiClientNode;
  friend class ZConfig;
  friend class ZBrowser;

  private:
    char CRLF[4];
    char LFCR[4];
    char LF[2];
    char CR[2];
    char BS=8;
    char ringCounter = 1;

    ZSerial serial;
    bool packetXOn = true;
    BinType binType = BTYPE_NORMAL;
    uint8_t nbuf[MAX_COMMAND_SIZE];
    char hbuf[MAX_COMMAND_SIZE];
    int eon=0;
    int lastServerClientId = 0;
    WiFiClientNode *current = null;
    bool autoStreamMode=false;
    bool telnetSupport=true;
    bool preserveListeners=false;
    unsigned long lastNonPlusTimeMs = 0;
    unsigned long currentExpiresTimeMs = 0;
    char *tempDelimiters = NULL;
    char *tempMaskOuts = NULL;
    char *tempStateMachine = NULL;
    char *delimiters = NULL;
    char *maskOuts = NULL;
    char *stateMachine = NULL;
    char *machineState = NULL;
    String machineQue = "";
    String previousCommand = "";
    WiFiClientNode *nextConn=null;
    int lastPacketId = -1;

    byte CRC8(const byte *data, byte len);

    void showInitMessage();
    bool readSerialStream();
    bool clearPlusProgress();
    bool checkPlusEscape();
    String getNextSerialCommand();
    ZResult doSerialCommand();
    void setConfigDefaults();
    void parseConfigOptions(String configArguments[]);
    void setOptionsFromSavedConfig(String configArguments[]);
    void reSaveConfig();
    void reSendLastPacket(WiFiClientNode *conn);
    void acceptNewConnection();
    void headerOut(const int channel, const int sz, const int crc8);
    void sendConnectionNotice(int nodeId);
    void sendNextPacket();
    void connectionArgs(WiFiClientNode *c);
    void updateAutoAnswer();
    uint8_t *doStateMachine(uint8_t *buf, int *bufLen, char **machineState, String *machineQue, char *stateMachine);
    uint8_t *doMaskOuts(uint8_t *buf, int *bufLen, char *maskOuts);
    ZResult doWebDump(Stream *in, int len, const bool cacheFlag);
    ZResult doWebDump(const char *filename, const bool cache);

    ZResult doResetCommand();
    ZResult doNoListenCommand();
    ZResult doBaudCommand(int vval, uint8_t *vbuf, int vlen);
    ZResult doTransmitCommand(int vval, uint8_t *vbuf, int vlen, bool isNumber, const char *dmodifiers, int *crc8);
    ZResult doLastPacket(int vval, uint8_t *vbuf, int vlen, bool isNumber);
    ZResult doConnectCommand(int vval, uint8_t *vbuf, int vlen, bool isNumber, const char *dmodifiers);
    ZResult doWiFiCommand(int vval, uint8_t *vbuf, int vlen, bool isNumber, const char *dmodifiers);
    ZResult doDialStreamCommand(unsigned long vval, uint8_t *vbuf, int vlen, bool isNumber, const char *dmodifiers);
    ZResult doPhonebookCommand(unsigned long vval, uint8_t *vbuf, int vlen, bool isNumber, const char *dmodifiers);
    ZResult doAnswerCommand(int vval, uint8_t *vbuf, int vlen, bool isNumber, const char *dmodifiers);
    ZResult doHangupCommand(int vval, uint8_t *vbuf, int vlen, bool isNumber);
    ZResult doEOLNCommand(int vval, uint8_t *vbuf, int vlen, bool isNumber);
    ZResult doInfoCommand(int vval, uint8_t *vbuf, int vlen, bool isNumber);
    ZResult doWebStream(int vval, uint8_t *vbuf, int vlen, bool isNumber, const char *filename, bool cache);
    ZResult doUpdateFirmware(int vval, uint8_t *vbuf, int vlen, bool isNumber);
    ZResult doTimeZoneSetupCommand(int vval, uint8_t *vbuf, int vlen, bool isNumber);

  public:
    int packetSize = 127;
    bool suppressResponses;
    bool numericResponses;
    bool longResponses;
    boolean doEcho;
    String EOLN;
    char EC='+';
    char ECS[32];

    ZCommand();
    void loadConfig();

    FlowControlType getFlowControlType();
    int getConfigFlagBitmap();

    void sendOfficialResponse(ZResult res);
    void serialIncoming();
    void loop();
    void reset();
};

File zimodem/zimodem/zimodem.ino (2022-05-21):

/*
   Copyright 2016-2019 Bo Zimmerman

   Licensed under the Apache License, Version 2.0 (the "License");
   you may not use this file except in compliance with the License.
   You may obtain a copy of the License at

     http://www.apache.org/licenses/LICENSE-2.0

   Unless required by applicable law or agreed to in writing, software
   distributed under the License is distributed on an "AS IS" BASIS,
   WITHOUT WARRANTIES OR CONDITIONS OF ANY KIND, either express or implied.
   See the License for the specific language governing permissions and
   limitations under the License. 
*/
//#define TCP_SND_BUF                     4 * TCP_MSS
#define ZIMODEM_VERSION "3.7.0"
const char compile_date[] = __DATE__ " " __TIME__;
#define DEFAULT_NO_DELAY true
#define null 0
//# define USE_DEVUPDATER true // only enable this if your name is Bo

#ifdef ARDUINO_ESP32_DEV
# define ZIMODEM_ESP32
#elif defined(ESP32)
# define ZIMODEM_ESP32
#elif defined(ARDUINO_ESP320)
# define ZIMODEM_ESP32
#elif defined(ARDUINO_NANO32)
# define ZIMODEM_ESP32
#elif defined(ARDUINO_LoLin32)
# define ZIMODEM_ESP32
#elif defined(ARDUINO_ESPea32)
# define ZIMODEM_ESP32
#elif defined(ARDUINO_QUANTUM)
# define ZIMODEM_ESP32
#else
# define ZIMODEM_ESP8266
#endif

#ifdef SUPPORT_LED_PINS
# ifdef GPIO_NUM_0
#   define DEFAULT_PIN_AA GPIO_NUM_16
#   define DEFAULT_PIN_HS GPIO_NUM_15
#   define DEFAULT_PIN_WIFI GPIO_NUM_0
# else
#   define DEFAULT_PIN_AA 16
#   define DEFAULT_PIN_HS 15
#   define DEFAULT_PIN_WIFI 0
# endif
# define DEFAULT_HS_BAUD 38400
# define DEFAULT_AA_ACTIVE LOW
# define DEFAULT_AA_INACTIVE HIGH
# define DEFAULT_HS_ACTIVE LOW
# define DEFAULT_HS_INACTIVE HIGH
# define DEFAULT_WIFI_ACTIVE LOW
# define DEFAULT_WIFI_INACTIVE HIGH
#endif

#ifdef ZIMODEM_ESP32
# define PIN_FACTORY_RESET GPIO_NUM_0
# define DEFAULT_PIN_DCD GPIO_NUM_14
# define DEFAULT_PIN_CTS GPIO_NUM_13
# define DEFAULT_PIN_RTS GPIO_NUM_15 // unused
# define DEFAULT_PIN_RI GPIO_NUM_32
# define DEFAULT_PIN_DSR GPIO_NUM_12
# define DEFAULT_PIN_DTR GPIO_NUM_27
# define debugPrintf Serial.printf
# define INCLUDE_SD_SHELL true
# define DEFAULT_FCT FCT_DISABLED
# define SerialConfig uint32_t
# define UART_CONFIG_MASK 0x8000000
# define UART_NB_BIT_MASK      0B00001100 | UART_CONFIG_MASK
# define UART_NB_BIT_5         0B00000000 | UART_CONFIG_MASK
# define UART_NB_BIT_6         0B00000100 | UART_CONFIG_MASK
# define UART_NB_BIT_7         0B00001000 | UART_CONFIG_MASK
# define UART_NB_BIT_8         0B00001100 | UART_CONFIG_MASK
# define UART_PARITY_MASK      0B00000011
# define UART_PARITY_NONE      0B00000000
# define UART_NB_STOP_BIT_MASK 0B00110000
# define UART_NB_STOP_BIT_0    0B00000000
# define UART_NB_STOP_BIT_1    0B00010000
# define UART_NB_STOP_BIT_15   0B00100000
# define UART_NB_STOP_BIT_2    0B00110000
# define preEOLN serial.prints
# define echoEOLN serial.write
//# define HARD_DCD_HIGH 1
//# define HARD_DCD_LOW 1
//# define INCLUDE_HOSTCM true // do this for special SP9000 modems only
#else  // ESP-8266, e.g. ESP-01, ESP-12E, inverted for C64Net WiFi Modem
# define DEFAULT_PIN_DSR 13
# define DEFAULT_PIN_DTR 12
# define DEFAULT_PIN_RI 14
# define DEFAULT_PIN_RTS 4
# define DEFAULT_PIN_CTS 5 // is 0 for ESP-01, see getDefaultCtsPin() below.
# define DEFAULT_PIN_DCD 2
# define DEFAULT_FCT FCT_RTSCTS
//# define RS232_INVERTED 1
# define debugPrintf doNothing
# define preEOLN(...)
# define echoEOLN(...) serial.prints(EOLN)
#endif

#ifdef RS232_INVERTED
# define DEFAULT_DCD_HIGH  HIGH
# define DEFAULT_DCD_LOW  LOW
# define DEFAULT_CTS_HIGH  HIGH
# define DEFAULT_CTS_LOW  LOW
# define DEFAULT_RTS_HIGH  HIGH
# define DEFAULT_RTS_LOW  LOW
# define DEFAULT_RI_HIGH  HIGH
# define DEFAULT_RI_LOW  LOW
# define DEFAULT_DSR_HIGH  HIGH
# define DEFAULT_DSR_LOW  LOW
# define DEFAULT_DTR_HIGH  HIGH
# define DEFAULT_DTR_LOW  LOW
#else
# define DEFAULT_DCD_HIGH  LOW
# define DEFAULT_DCD_LOW  HIGH
# define DEFAULT_CTS_HIGH  LOW
# define DEFAULT_CTS_LOW  HIGH
# define DEFAULT_RTS_HIGH  LOW
# define DEFAULT_RTS_LOW  HIGH
# define DEFAULT_RI_HIGH  LOW
# define DEFAULT_RI_LOW  HIGH
# define DEFAULT_DSR_HIGH  LOW
# define DEFAULT_DSR_LOW  HIGH
# define DEFAULT_DTR_HIGH  LOW
# define DEFAULT_DTR_LOW  HIGH
#endif

#define DEFAULT_BAUD_RATE 19200
#define DEFAULT_SERIAL_CONFIG SERIAL_8N1
#define MAX_PIN_NO 50
#define INTERNAL_FLOW_CONTROL_DIV 380
#define DEFAULT_RECONNECT_DELAY 5000
#define MAX_RECONNECT_DELAY 1800000

class ZMode
{
  public:
    virtual void serialIncoming();
    virtual void loop();
};

#include "pet2asc.h"
#include "rt_clock.h"
#include "filelog.h"
#include "serout.h"
#include "connSettings.h"
#include "wificlientnode.h"
#include "stringstream.h"
#include "phonebook.h"
#include "wifiservernode.h"
#include "zstream.h"
#include "proto_http.h"
#include "proto_ftp.h"
#include "zcommand.h"
#include "zconfigmode.h"
#include "zprint.h"

#ifdef INCLUDE_SD_SHELL
#  ifdef INCLUDE_HOSTCM
#    include "zhostcmmode.h"
#  endif
#  include "proto_xmodem.h"
#  include "proto_zmodem.h"
#  include "proto_kermit.h"
#  include "zbrowser.h"
#endif
#  ifdef INCLUDE_SLIP
#    include "zslipmode.h"
#  endif

static WiFiClientNode *conns = null;
static WiFiServerNode *servs = null;
static PhoneBookEntry *phonebook = null;
static bool pinSupport[MAX_PIN_NO];
static bool browseEnabled = false;
static String termType = DEFAULT_TERMTYPE;
static String busyMsg = DEFAULT_BUSYMSG;

static ZMode *currMode = null;
static ZStream streamMode;
//static ZSlip slipMode; // not yet implemented
static ZCommand commandMode;
static ZPrint printMode;
static ZConfig configMode;
static RealTimeClock zclock(0);
#ifdef INCLUDE_SD_SHELL
#  ifdef INCLUDE_HOSTCM
     static ZHostCMMode hostcmMode;
#  endif
   static ZBrowser browseMode;
#endif
#ifdef INCLUDE_SLIP
   static ZSLIPMode slipMode;
#endif

enum BaudState
{
  BS_NORMAL,
  BS_SWITCH_TEMP_NEXT,
  BS_SWITCHED_TEMP,
  BS_SWITCH_NORMAL_NEXT
};

static String wifiSSI;
static String wifiPW;
static String hostname;
static IPAddress *staticIP = null;
static IPAddress *staticDNS = null;
static IPAddress *staticGW = null;
static IPAddress *staticSN = null;
static unsigned long lastConnectAttempt = 0;
static unsigned long nextReconnectDelay = 0; // zero means don't attempt reconnects
static SerialConfig serialConfig = DEFAULT_SERIAL_CONFIG;
static int baudRate=DEFAULT_BAUD_RATE;
static int dequeSize=1+(DEFAULT_BAUD_RATE/INTERNAL_FLOW_CONTROL_DIV);
static BaudState baudState = BS_NORMAL; 
static unsigned long resetPushTimer=0;
static int tempBaud = -1; // -1 do nothing
static int dcdStatus = LOW;
static int pinDCD = DEFAULT_PIN_DCD;
static int pinCTS = DEFAULT_PIN_CTS;
static int pinRTS = DEFAULT_PIN_RTS;
static int pinDSR = DEFAULT_PIN_DSR;
static int pinDTR = DEFAULT_PIN_DTR;
static int pinRI = DEFAULT_PIN_RI;
static int dcdActive = DEFAULT_DCD_HIGH;
static int dcdInactive = DEFAULT_DCD_LOW;
static int ctsActive = DEFAULT_CTS_HIGH;
static int ctsInactive = DEFAULT_CTS_LOW;
static int rtsActive = DEFAULT_RTS_HIGH;
static int rtsInactive = DEFAULT_RTS_LOW;
static int riActive = DEFAULT_RI_HIGH;
static int riInactive = DEFAULT_RI_LOW;
static int dtrActive = DEFAULT_DTR_HIGH;
static int dtrInactive = DEFAULT_DTR_LOW;
static int dsrActive = DEFAULT_DSR_HIGH;
static int dsrInactive = DEFAULT_DSR_LOW;

static int getDefaultCtsPin()
{
#ifdef ZIMODEM_ESP32
  return DEFAULT_PIN_CTS;
#else
  if((ESP.getFlashChipRealSize()/1024)>=4096) // assume this is a striketerm/esp12e
    return DEFAULT_PIN_CTS;
  else
    return 0;
#endif 
}

static void doNothing(const char* format, ...) 
{
}

static void s_pinWrite(uint8_t pinNo, uint8_t value)
{
  if(pinSupport[pinNo])
  {
    digitalWrite(pinNo, value);
  }
}

static void setHostName(const char *hname)
{
#ifdef ZIMODEM_ESP32
      tcpip_adapter_set_hostname(TCPIP_ADAPTER_IF_STA, hname);
#else
      WiFi.hostname(hname);
#endif
}

static void setNewStaticIPs(IPAddress *ip, IPAddress *dns, IPAddress *gateWay, IPAddress *subNet)
{
  if(staticIP != null)
    free(staticIP);
  staticIP = ip;
  if(staticDNS != null)
    free(staticDNS);
  staticDNS = dns;
  if(staticGW != null)
    free(staticGW);
  staticGW = gateWay;
  if(staticSN != null)
    free(staticSN);
  staticSN = subNet;
}

static bool connectWifi(const char* ssid, const char* password, IPAddress *ip, IPAddress *dns, IPAddress *gateWay, IPAddress *subNet)
{
  while(WiFi.status() == WL_CONNECTED)
  {
    WiFi.disconnect();
    delay(100);
    yield();
  }
#ifndef ZIMODEM_ESP32
  if(hostname.length() > 0)
    setHostName(hostname.c_str());
#endif
  WiFi.mode(WIFI_STA);
  if((ip != null)&&(gateWay != null)&&(dns != null)&&(subNet!=null))
  {
    if(!WiFi.config(*ip,*gateWay,*subNet,*dns))
      return false;
  }
  WiFi.begin(ssid, password);
  if(hostname.length() > 0)
    setHostName(hostname.c_str());
  bool amConnected = (WiFi.status() == WL_CONNECTED) && (strcmp(WiFi.localIP().toString().c_str(), "0.0.0.0")!=0);
  int WiFiCounter = 0;
  while ((!amConnected) && (WiFiCounter < 20))
  {
    WiFiCounter++;
    if(!amConnected)
      delay(500);
    amConnected = (WiFi.status() == WL_CONNECTED) && (strcmp(WiFi.localIP().toString().c_str(), "0.0.0.0")!=0);
  }
  lastConnectAttempt = millis();
  if(lastConnectAttempt == 0)
    lastConnectAttempt = 1; // 0 is a special case, so skip it

  if(!amConnected)
  {
    nextReconnectDelay = 0; // assume no retry is desired.. let the caller set it up, as it could be bad PW
    WiFi.disconnect();
  }
  else
    nextReconnectDelay = DEFAULT_RECONNECT_DELAY; // if connected, we always want to try reconns in the future

#ifdef SUPPORT_LED_PINS
  s_pinWrite(DEFAULT_PIN_WIFI,(WiFi.status() == WL_CONNECTED)?DEFAULT_WIFI_ACTIVE:DEFAULT_WIFI_INACTIVE);
#endif
  return (WiFi.status() == WL_CONNECTED);
}

static void checkBaudChange()
{
  switch(baudState)
  {
    case BS_SWITCH_TEMP_NEXT:
      changeBaudRate(tempBaud);
      baudState = BS_SWITCHED_TEMP;
      break;
    case BS_SWITCH_NORMAL_NEXT:
      changeBaudRate(baudRate);
      baudState = BS_NORMAL;
      break;
    default:
      break;
  }
}

static void changeBaudRate(int baudRate)
{
  flushSerial(); // blocking, but very very necessary
  delay(500); // give the client half a sec to catch up
  logPrintfln("Baud change to %d.\n",baudRate);
  debugPrintf("Baud change to %d.\n",baudRate);
  dequeSize=1+(baudRate/INTERNAL_FLOW_CONTROL_DIV);
  debugPrintf("Deque constant now: %d\n",dequeSize);
#ifdef ZIMODEM_ESP32
  HWSerial.changeBaudRate(baudRate);
#else
  HWSerial.begin(baudRate, serialConfig);  //Change baud rate
#endif
#ifdef SUPPORT_LED_PINS
  s_pinWrite(DEFAULT_PIN_HS,(baudRate>=DEFAULT_HS_BAUD)?DEFAULT_HS_ACTIVE:DEFAULT_HS_INACTIVE);
#endif  
}

static void changeSerialConfig(SerialConfig conf)
{
  flushSerial(); // blocking, but very very necessary
  delay(500); // give the client half a sec to catch up
  debugPrintf("Config changing %d.\n",(int)conf);
  dequeSize=1+(baudRate/INTERNAL_FLOW_CONTROL_DIV);
  debugPrintf("Deque constant now: %d\n",dequeSize);
#ifdef ZIMODEM_ESP32
  HWSerial.changeConfig(conf);
#else
  HWSerial.begin(baudRate, conf);  //Change baud rate
#endif  
  debugPrintf("Config changed.\n");
}

static int checkOpenConnections()
{
  int num=WiFiClientNode::getNumOpenWiFiConnections();
  if(num == 0)
  {
    if((dcdStatus == dcdActive)
    &&(dcdStatus != dcdInactive))
    {
      logPrintfln("DCD going inactive.\n");
      dcdStatus = dcdInactive;
      s_pinWrite(pinDCD,dcdStatus);
      if(baudState == BS_SWITCHED_TEMP)
        baudState = BS_SWITCH_NORMAL_NEXT;
      if(currMode == &commandMode)
        clearSerialOutBuffer();
    }
  }
  else
  {
    if((dcdStatus == dcdInactive)
    &&(dcdStatus != dcdActive))
    {
      logPrintfln("DCD going active.\n");
      dcdStatus = dcdActive;
      s_pinWrite(pinDCD,dcdStatus);
      if((tempBaud > 0) && (baudState == BS_NORMAL))
        baudState = BS_SWITCH_TEMP_NEXT;
    }
  }
  return num;
}

void setup() 
{
  for(int i=0;i<MAX_PIN_NO;i++)
    pinSupport[i]=false;
#ifdef ZIMODEM_ESP32
  Serial.begin(115200); //the debug port
  Serial.setDebugOutput(true);
  debugPrintf("Debug port open and ready.\n");
  for(int i=12;i<=23;i++)
    pinSupport[i]=true;
  for(int i=25;i<=27;i++)
    pinSupport[i]=true;
  for(int i=32;i<=33;i++)
    pinSupport[i]=true;
  pinSupport[36]=true;
  pinSupport[39]=true;
#else
  pinSupport[0]=true;
  pinSupport[2]=true;
  if((ESP.getFlashChipRealSize()/1024)>=4096) // assume this is a strykelink/esp12e
  {
    pinSupport[4]=true;
    pinSupport[5]=true;
    for(int i=9;i<=16;i++)
      pinSupport[i]=true;
    pinSupport[11]=false;
  }
#endif    
  initSDShell();
  currMode = &commandMode;
  if(!SPIFFS.begin())
  {
    SPIFFS.format();
    SPIFFS.begin();
    debugPrintf("SPIFFS Formatted.");
  }
  HWSerial.begin(DEFAULT_BAUD_RATE, DEFAULT_SERIAL_CONFIG);  //Start Serial
#ifdef ZIMODEM_ESP8266
  HWSerial.setRxBufferSize(1024);
#endif
  commandMode.loadConfig();
  PhoneBookEntry::loadPhonebook();
  dcdStatus = dcdInactive;
  s_pinWrite(pinDCD,dcdStatus);
  flushSerial();
#ifdef SUPPORT_LED_PINS
  s_pinWrite(DEFAULT_PIN_WIFI,(WiFi.status() == WL_CONNECTED)?DEFAULT_WIFI_ACTIVE:DEFAULT_WIFI_INACTIVE);
  s_pinWrite(DEFAULT_PIN_HS,(baudRate>=DEFAULT_HS_BAUD)?DEFAULT_HS_ACTIVE:DEFAULT_HS_INACTIVE);
#endif
}

void checkReconnect()
{
  if((WiFi.status() != WL_CONNECTED)
  &&(nextReconnectDelay>0)
  &&(lastConnectAttempt>0)
  &&(wifiSSI.length()>0))
  {
     unsigned long now=millis();
     if(lastConnectAttempt > now)
       lastConnectAttempt=1;
     if(now > lastConnectAttempt + nextReconnectDelay)
     {
        debugPrintf("Attempting Reconnect to %s\n",wifiSSI.c_str());
        unsigned long oldReconnectDelay = nextReconnectDelay;
        if(!connectWifi(wifiSSI.c_str(),wifiPW.c_str(),staticIP,staticDNS,staticGW,staticSN))
          debugPrintf("%sUnable to reconnect to %s.\n",wifiSSI.c_str());
        nextReconnectDelay = oldReconnectDelay * 2;
        if(nextReconnectDelay > MAX_RECONNECT_DELAY)
          nextReconnectDelay = DEFAULT_RECONNECT_DELAY;
     }
  }
}

void checkFactoryReset()
{
#ifdef ZIMODEM_ESP32
    if(!digitalRead(PIN_FACTORY_RESET))
    {
      if(resetPushTimer != 1)
      {
        if(resetPushTimer==0)
        {
          resetPushTimer=millis();
          if(resetPushTimer==1)
            resetPushTimer++;
        }
        else
        if((millis() - resetPushTimer) > 5000)
        {
          SPIFFS.remove(CONFIG_FILE);
          SPIFFS.remove(CONFIG_FILE_OLD);
          SPIFFS.remove("/zphonebook.txt");
          SPIFFS.remove("/zlisteners.txt");
          PhoneBookEntry::clearPhonebook();
          SPIFFS.end();
          SPIFFS.format();
          SPIFFS.begin();
          PhoneBookEntry::clearPhonebook();
          if(WiFi.status() == WL_CONNECTED)
            WiFi.disconnect();
          baudRate = DEFAULT_BAUD_RATE;
          commandMode.loadConfig();
          PhoneBookEntry::loadPhonebook();
          dcdStatus = dcdInactive;
          s_pinWrite(pinDCD,dcdStatus);
          wifiSSI="";
          delay(500);
          zclock.reset();
          commandMode.reset();
          resetPushTimer=1;
        }
      }
    }
    else
    if(resetPushTimer != 0)
      resetPushTimer=0;
#endif
}

void loop() 
{
  checkFactoryReset();
  checkReconnect();
  if(HWSerial.available())
  {
    currMode->serialIncoming();
  }
  currMode->loop();
  zclock.tick();
}

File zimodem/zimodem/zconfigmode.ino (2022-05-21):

/*
   Copyright 2016-2019 Bo Zimmerman

   Licensed under the Apache License, Version 2.0 (the "License");
   you may not use this file except in compliance with the License.
   You may obtain a copy of the License at

     http://www.apache.org/licenses/LICENSE-2.0

   Unless required by applicable law or agreed to in writing, software
   distributed under the License is distributed on an "AS IS" BASIS,
   WITHOUT WARRANTIES OR CONDITIONS OF ANY KIND, either express or implied.
   See the License for the specific language governing permissions and
   limitations under the License.
*/

void ZConfig::switchTo()
{
  currMode=&configMode;
  serial.setFlowControlType(commandMode.serial.getFlowControlType());
  serial.setPetsciiMode(commandMode.serial.isPetsciiMode());
  savedEcho=commandMode.doEcho;
  newListen=commandMode.preserveListeners;
  commandMode.doEcho=true;
  serverSpec.port=6502;
  serverSpec.flagsBitmap=commandMode.getConfigFlagBitmap();
  if(servs)
    serverSpec = *servs;
  serial.setXON(true);
  showMenu=true;
  EOLN=commandMode.EOLN;
  EOLNC=EOLN.c_str();
  currState = ZCFGMENU_MAIN;
  lastNumber=0;
  lastAddress="";
  lastOptions="";
  settingsChanged=false;
  lastNumNetworks=0;
}

void ZConfig::serialIncoming()
{
  bool crReceived=commandMode.readSerialStream();
  commandMode.clearPlusProgress(); // re-check the plus-escape mode
  if(crReceived)
  {
    doModeCommand();
  }
}

void ZConfig::switchBackToCommandMode()
{
  commandMode.doEcho=savedEcho;
  currMode = &commandMode;
}

void ZConfig::doModeCommand()
{
  String cmd = commandMode.getNextSerialCommand();
  char c='?';
  for(int i=0;i<cmd.length();i++)
  {
    if(cmd[i]>32)
    {
      c=lc(cmd[i]);
      break;
    }
  }
  switch(currState)
  {
    case ZCFGMENU_MAIN:
    {
      if((c=='q')||(cmd.length()==0))
      {
        if(settingsChanged)
        {
          currState=ZCFGMENU_WICONFIRM;
          showMenu=true;
        }
        else
        {
          commandMode.showInitMessage();
          switchBackToCommandMode();
          return;
        }
      }
      else
      if(c=='a') // add to phonebook
      {
        currState=ZCFGMENU_NUM;
        showMenu=true;
      }
      else
      if(c=='w') // wifi
      {
        currState=ZCFGMENU_WIMENU;
        showMenu=true;
      }
      else
      if(c=='h') // host
      {
        currState=ZCFGMENU_NEWHOST;
        showMenu=true;
      }
      else
      if(c=='f') // flow control
      {
        currState=ZCFGMENU_FLOW;
        showMenu=true;
      }
      else
      if(c=='p') // petscii translation toggle
      {
        commandMode.serial.setPetsciiMode(!commandMode.serial.isPetsciiMode());
        serial.setPetsciiMode(commandMode.serial.isPetsciiMode());
        settingsChanged=true;
        showMenu=true;
      }
      else
      if(c=='e') // echo
      {
        savedEcho = !savedEcho;
        settingsChanged=true;
        showMenu=true;
      }
      else
      if(c=='b') // bbs
      {
        currState=ZCFGMENU_BBSMENU;
        showMenu=true;
      }
      else
      if(c>47 && c<58) // its a phonebook entry!
      {
        PhoneBookEntry *pb=PhoneBookEntry::findPhonebookEntry(cmd);
        if(pb == null)
        {
          serial.printf("%s%sPhone number not found: '%s'.%s%s",EOLNC,EOLNC,cmd.c_str(),EOLNC,EOLNC);
          currState=ZCFGMENU_MAIN;
          showMenu=true;
        }
        else
        {
          lastNumber = pb->number;
          lastAddress = pb->address;
          lastOptions = pb->modifiers;
          lastNotes = pb->notes;
          currState=ZCFGMENU_ADDRESS;
          showMenu=true;
        }
      }
      else
      {
        showMenu=true; // re-show the menu
      }
      break;
    }
    case ZCFGMENU_WICONFIRM:
    {
      if((cmd.length()==0)||(c=='n'))
      {
        commandMode.showInitMessage();
        switchBackToCommandMode();
        return;
      }
      else
      if(c=='y')
      {
        if(newListen != commandMode.preserveListeners)
        {
          commandMode.preserveListeners=newListen;
          if(!newListen)
          {
            SPIFFS.remove("/zlisteners.txt");
            WiFiServerNode::DestroyAllServers();
          }
          else
          {
            commandMode.ringCounter=1;
            commandMode.autoStreamMode=true;
            WiFiServerNode *s=WiFiServerNode::FindServer(serverSpec.port);
            if(s != null)
              delete s;
            s = new WiFiServerNode(serverSpec.port,serverSpec.flagsBitmap);
            WiFiServerNode::SaveWiFiServers();
          }
        }
        else
        if(commandMode.preserveListeners)
        {
          WiFiServerNode *s = WiFiServerNode::FindServer(serverSpec.port);
          if( s != null)
          {
            if(s->flagsBitmap != serverSpec.flagsBitmap)
            {
              s->flagsBitmap = serverSpec.flagsBitmap;
            }
          }
          else
          {
            WiFiServerNode::DestroyAllServers();
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

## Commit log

2020-08-01 Moving to Non Forked Copy of Zimodem
    [Link232-Wifi-BottomCase-Number4screw.stl, Link232-Wifi-TopCase.stl, Link232-Wifi-cartridge-bottom.stl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]
2020-08-02 Sync And Fixes
    Sync to Zimodem release as of (08-01-2020).
    Fixed the following bugs.
    DCD wasn't being raised if the connection was made using the ATA command.
    When CTS/RTS is enabled on the Link232-Wifi, the NO CARRIER response for the modem was cut off after 2 characters.
    [zimodem.ino]
2020-08-02 Sync And Fixes (2)
    Sync to Zimodem release as of (08-01-2020). For real this time.. oops.
    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
    [zcommand.h, zcommand.ino, zimodem.ino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]
2020-12-29 Upgrade to Zimodem 3.5.6
    Upgrade to zimodem 3.5.6
    Includes stream fix by Fix broken up sending of escape sequences by hanshuebner.
    Also has DCD fix on manual answer fix.
    [proto_zmodem.ino, zcommand.ino, zimodem.ino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]
2021-02-07 Update Link232-Manual-Firmware-Update.pdf
    Clarify a couple of steps.
2021-11-23 Delete Link232-Wifi-cartridge-bottom.stl
    Incorrect model.
    [Link232-Wifi-cartridge-bottom.stl]
2022-05-20 Internal Modem directories renamed.
    [Link232-wifi-c64.brd, Link232-wifi-c64.sch, Link232-wifi.brd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]
2023-01-13 Updated Driver Notes
2023-04-26 Added Centipede drivers for DF00/D700
    Added SoftwarePatches directory.

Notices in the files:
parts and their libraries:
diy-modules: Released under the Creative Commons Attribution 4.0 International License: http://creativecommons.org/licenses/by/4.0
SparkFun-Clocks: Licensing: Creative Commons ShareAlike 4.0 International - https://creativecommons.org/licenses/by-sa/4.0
